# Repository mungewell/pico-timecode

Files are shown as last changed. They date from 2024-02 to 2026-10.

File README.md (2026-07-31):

# What is 'Pico-Timecode'?

'Pico-Timecode' is an Open-Source solution for LTC Timecode, using the RP2040's PIO blocks to count time divisions and render the LTC waveform. It works with all common frame rates, with/with-out Drop-Frame operation. It also has the ability to read LTC from an external device, and sync to it.

_LTC (sometimes refered to as SMPTE Timecode) is used in the TV/Movie industry as a way to synchronize video and audio recordings, it offers improvements in workflow and (most importantly) decreases overall editing time._

Some pro-consumer/professional Timecode devices use wireless links; Pico-Timecode is 'old skool' it uses a cabled connection to record the LTC signal onto an audio track of your camera or audio recorder. This audio waveform can later be processed and used to align multiple clips. If your device supports a true LTC input the data will be written directly as meta-data into the file(s).

For more information, check out the [Wiki.](https://github.com/mungewell/pico-timecode/wiki)

# Hardware

This technology has been implemented in 2 custom PCBs; Firstly the (now renamed) 'PT-Papa' board based around the (full sized) Raspberry Pico board, with Waveshare OLED screen module and input/output connectors.

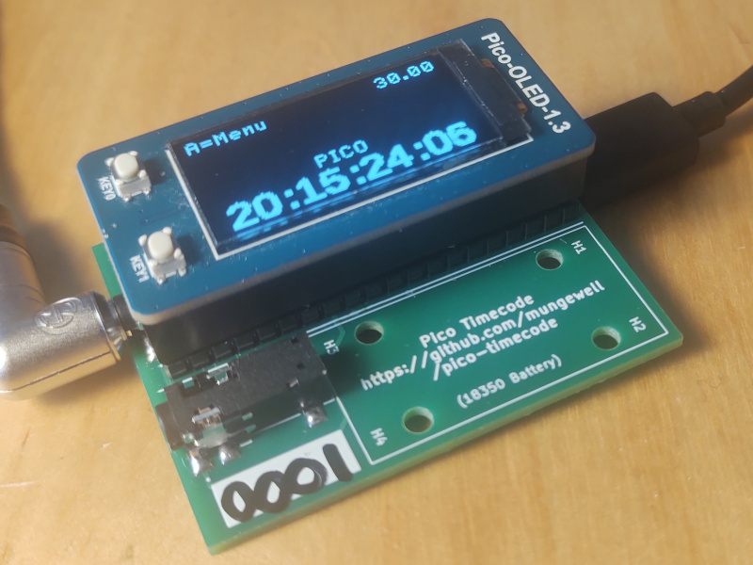
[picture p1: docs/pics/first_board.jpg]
'pt-papa' board


Secondly with the 'PT-Thrifty' board based around the (mini sized) Waveshare RP2040-Zero. 'PT-Thrifty' aims to make LTC accessible to DIY/budget film-makers, and thus it uses a minimum of components. It has a UI with single button and RGB LED, the control of the device is achieved by navigating through a [UI 'map'](https://github.com/mungewell/pico-timecode/blob/main/docs/pics/PT_Thrifty_UI.png) of states. 

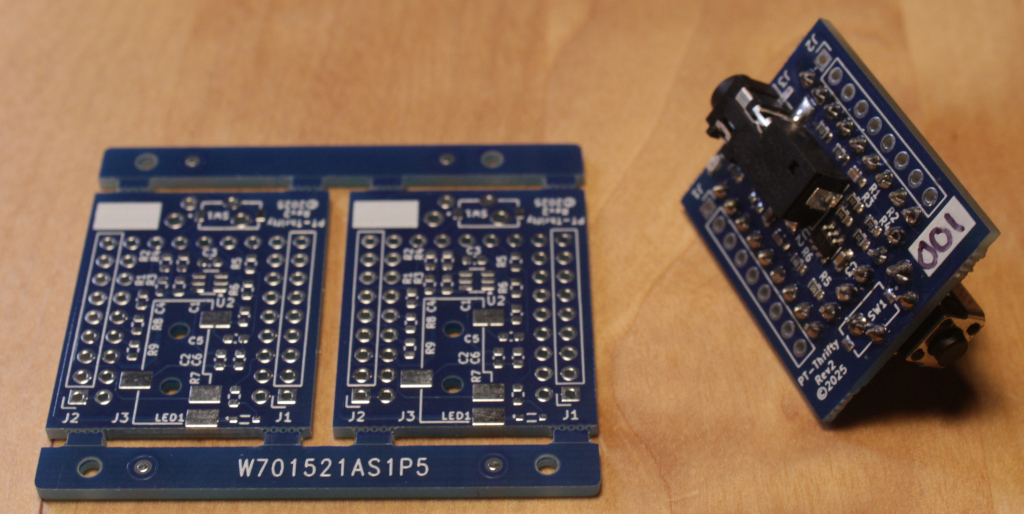
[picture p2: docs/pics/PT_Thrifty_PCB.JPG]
'pt-thrifty' board


There are some demonstrations of 'PT-Thrifty' [here.](https://www.youtube.com/playlist?list=PL1t1GwpUNc-VbEAXxscaxrPQlrt16c4yX)

# DIY yours now...

As the project is Open-Source, it's intended to be customized for other implementations.

The code as it is can be run on any RP2040 board, though may need customization for particular use cases. The easiest/fastest route to try it out is to use the PT_Thrifty '.UF2' files on the releases page, these can be run on a 'naked' Pico and will even sync LTC between multi Picos - albeit it at 3.3V TTL level. You will need at least a mininal amount of interface circuitry to record the signal on your camera or audio recorder.

I recomend replacing the XTAL on the Pico with a TCXO, but once 'calibrated' even the XTAL will hold time OK for a few hours.

To install the code to your Pico from source, at minimum you need to copy/install the `libs` directory, `pico-timecode.py` and **either** `pt_papa.py` or `pt_thrifty.py` (which should be renamed as `main.py` so that it runs at boot time).

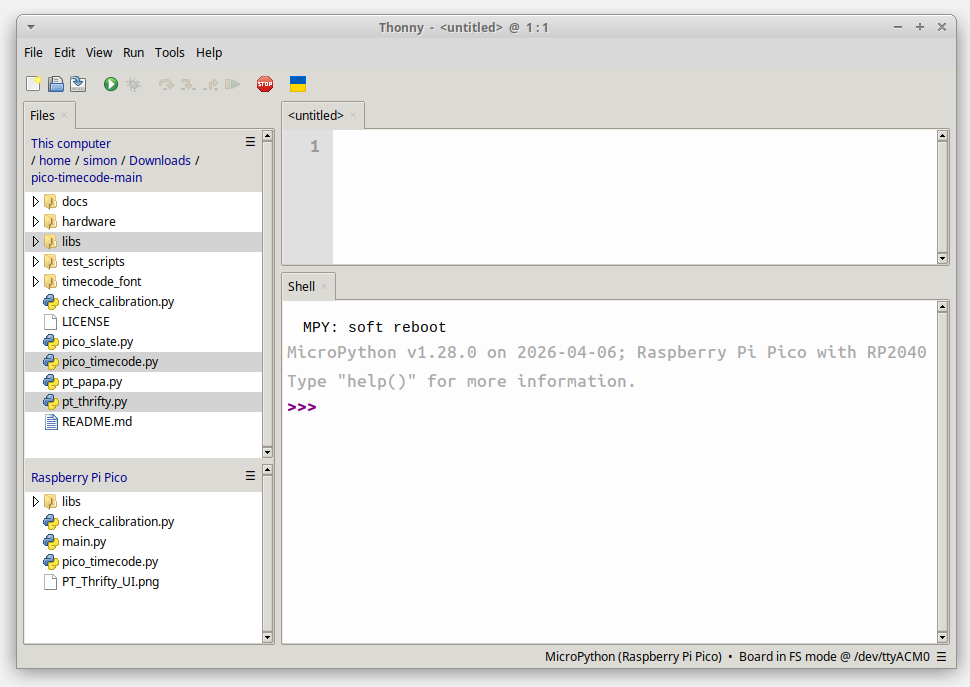
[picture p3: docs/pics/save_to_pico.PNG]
Install the code


# Why?

Why am doing this? Primarily because it's a fun challenge. I've been interested in Timecode for a while and the PIO blocks on the Pico are very powerfull. I am debating whether to offer pre-built hardware for purchase, *at very reasonable costs*.

You can follow the project on [Instagram.](https://www.instagram.com/picotimecode/)

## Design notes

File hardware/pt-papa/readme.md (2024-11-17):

Work is starting on PCB Rev2, for a while these files may be incomplete. You can access the
Rev1 PCB here:

https://github.com/mungewell/pico-timecode/releases/tag/PCB_Rev1

Ideas for future:

- 2x button on the bottom side, for replicating A & B when used with RP2040-LCD-0.96

- pull down 0R on U2/5 nCS, to allow 3rd party to wire line if SD0 is also used for other devices.

- add battery holder connections/through holes

- connections for Digi-Slate (extra) 8x 7-seg LED.

    This lib looks very interesting:
    https://github.com/smittytone/HT16K33-Python

    display count when switch is open, then hold for 2s once closed, then turn off
    possibly display UB, though could only do Digits/BCD.

    would need I2C (GP0, 1) and GPIO (GP2), plus GND/3.3v/VSYS

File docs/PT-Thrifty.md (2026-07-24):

# The PT-Thrifty is the 'lowest cost Timecode'.

PT-Thrifty has a single 3.5mm jack, from power on this outputs LTC
timecode. At different times of operation the 3.5mm jack becomes an
input, so that the PT-Thrifty can be 'Jam-Synced' from another LTC 
device.

User interface is a single button and a RGB LED, with some actions
requiring connecting/dis-connecting the 3.5mm jack.

There is a 2nd LED next to the 3.5mm jack. This provides a 1PPS flash
from the internal LTC timers at the start of Frame-0. As this is driven
directly its timing is exact, but some commercial units (ie: UltraSync)
choose to blink on Frame-11 for some reason... this can be configured through the `libs/config.py' file.

PT-Thifty is designed to be _LOW COST_, so it does not include battery
or other features that are technically possible (although these can 
be added to your DIY-ed version). The unit needs to be (and remain) externally powered for the duration 
of the shoot. If power is lost the unit will need to be Jam-Synced again.

Note: the 'Info' RGB will double-flash if the unit has previously been Jam-Synced.

[Video Demo](https://youtube.com/shorts/oo_elmEAXs4?feature=share)

# Map of the UI

In pictorial form the UI looks like:

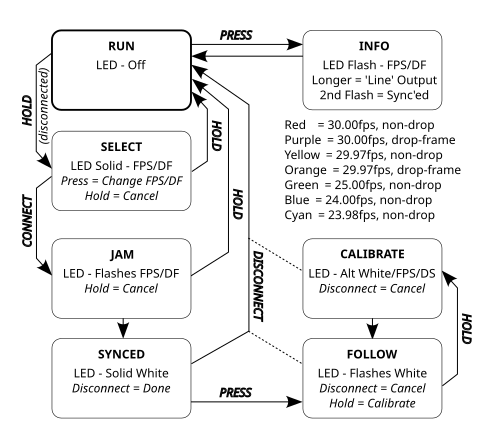
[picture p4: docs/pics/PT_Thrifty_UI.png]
Map


## Run, and Info

When initially powered up, the PT-Thrifty will start outputing LTC
timecode - this is NOT schronized with anything, just a free running
clock/counter.

Upon power up the RGB LED will flash a colour to inform the user what 
FPS and DropFrame configuration is active:

- Red 	= 30.00fps, non-drop
- Purple	= 30.00fps, drop-frame
- Yellow	= 29.97fps, non-drop
- Orange	= 29.97fps, drop-frame
- Green	= 25.00fps, non-drop
- Blue	= 24.00fps, non-drop
- Cyan	= 23.98fps, non-drop

Note: Some Pico boards use 'RGB' and some use 'GRB', this is configurable and should be changed if the sequence of FPS colours is not as above.

At any time during 'Run' the user can press the button to be reminded
of the current configuration ('Info').

To 'Jam' to another unit, disconnect the 3.5mm jack and press-and-hold 
the button until the LED becomes a steady colour. Then connect the 3.5mm
jack from the 'Master LTC', the LED will flash the colour and then become
solid white when the 'Jam' is complete.

Note: once solid white is displayed the internal time is set, but the LTC 
is not output until the 3.5mm jack is disconnected, and then the connection 
to camera/recorder is remade. Then PT-Thrift will then output LTC.

## Output Level

PT-Thrifty has two output levels: by default 'Mic' (~80mV pk-pk) and, optionally, 'Line' (1V pk-pk).

In order to change the output level the unit must be power-cycled. The
output level is toggled 'Mic' <-> 'Line' when the button is held during 
booting, and the current level is indicated during 'Info'.

The 'Info' flash is longer (0.3s vs 0.1s) when the output level is 'Line'. *The 2nd 'Jam-Synced' flash will remain at 0.1s duration, as a comparison aid.*

## Changing FPS and Drop-Frame configuration

As part of the 'Jam' process the FPS and Drop-Frame configuration can
be changed. From 'Run', hold the button until LED is solid colour and then
each press of the button will cycle through the available configurations.

When the desired configuration is reached, connect the 3.5mm jack to 
start jamming with the new configuration. This new configuration will be 
remembered for the next time PT-Thrifty powers on.

Note: During this 'Pre-Jam' selection, the internal LTC time is still
correct. If a user enters this state and changes their mind they can 
long-press the button to return to the 'Run' state, without loosing LTC synchronization. 

Note: If the unit enters the 'Jam' mode (flashing Colour), then the 
internal **LTC time is lost** and the unit will NOT be Synchronised until
it is Jam-Synced with an external unit.

## Calibration

Typicaly the TCXO module inside PT-Thrifty is accurate to under +/-0.5
frames of drift over a 12 hour period.

However if the user has DIY-ed a board, they may be using the stock/passive
XTAL that the RP2040 boards normally have. This will be inaccurate, but
can be 'Calibrated' to match a more accurate source such as commercial
LTC device.

A calibrated DIY/XTAL unit is only accurate for a few hours, and is likely 
temperature dependant. If the user goes between a warm and cold ambient 
temperature, the LTC will drift away faster from the correct value.

Once the 'Jam' has completed, shown by solid white LED, a button press
will enter 'Follow' mode. During 'Follow' the LTC produced by PT-Thrifty
will be adjusted to match incoming LTC.

Disconnect the 3.5mm jack to return to 'Run' mode.

Note: during 'Follow' the rate of the incoming LTC is tracked, PT-Thrifty does not update if there is a "jump change" in the incoming LTC.

Note: as the LTC is not output at this time, this is just informative
and the relationship of RX vs. TX LTC will be relayed to the serial port.

A long-press will enter 'Calibrate' mode, which like 'Follow', the internal 
LTC rate will be adjusted to match incoming LTC rate. This is indicated with 
alternate White/Colour flashing.

After ~10mins of processing, the new calibration value will be stored and 
the unit will return to 'Follow' mode. Disconnect the 3.5mm jack to 
return to 'Run' mode.

Note: To clear a calibration the user needs to enter 'Calibration' mode, 
but then disconnect the 3.5mm jack BEFORE it completes the calibration 
process.

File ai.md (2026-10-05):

AI declaration: Simon Wood (simon@mungewell.org), 2026-10-05.

Within are my views on AI contributions to this project. 

Open-Source relies on the legal framework of copyright to enforce it's licenses. And for that reason I will not accept submissions from AI-agents or code from Generative-AI, as the former can not make legal assignments of copyright and the later can not prove where it 'sourced' the code/information.

Using this other (random) reference:
- https://www.visidata.org/blog/2026/ai/
- https://web.archive.org/web/20260925032610/https://www.visidata.org/blog/2026/ai/

The 'levels of AI' in submissions are limited to:
- Level 0: Human did not use AI at all
- Level 1: Human asked chatbot for ideas
- Level 2: Human coded with minor assists

Ultimately this is my project, I reserve the right to reject any submissions.

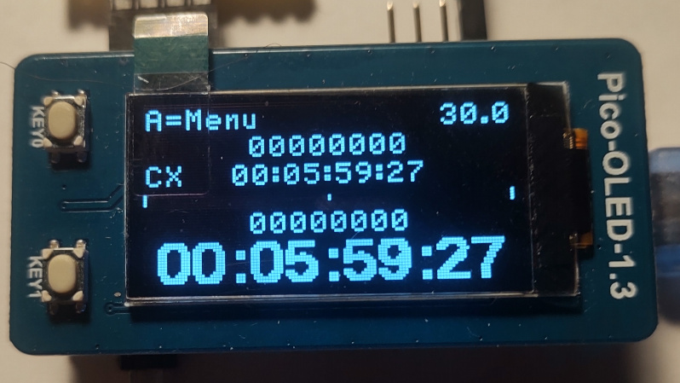
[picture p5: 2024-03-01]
docs/pics/prototype_hardware.jpg

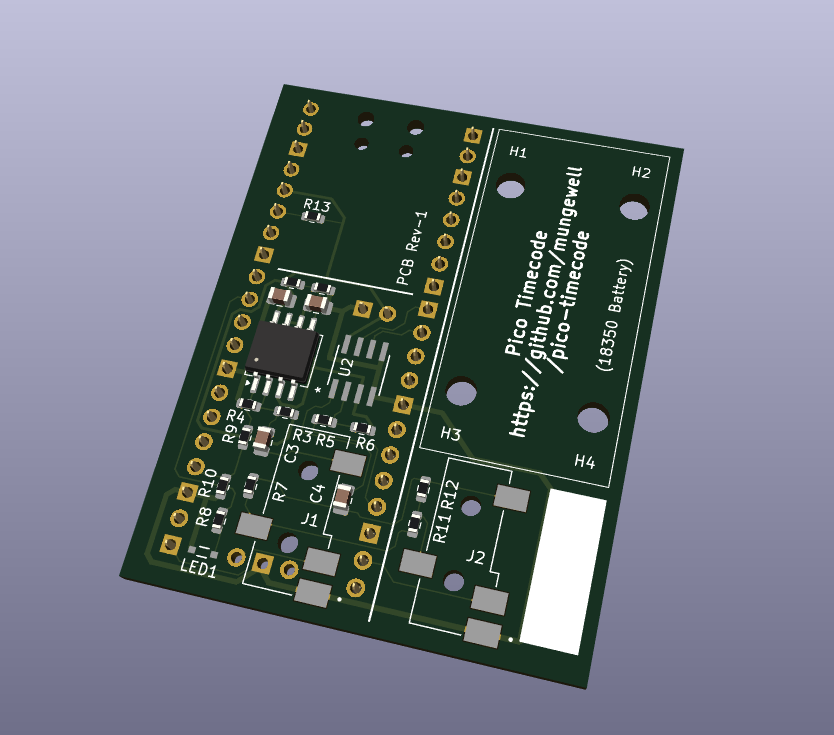
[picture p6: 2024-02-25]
hardware/pt-papa/output_pcb_rev1/rev1-render.png

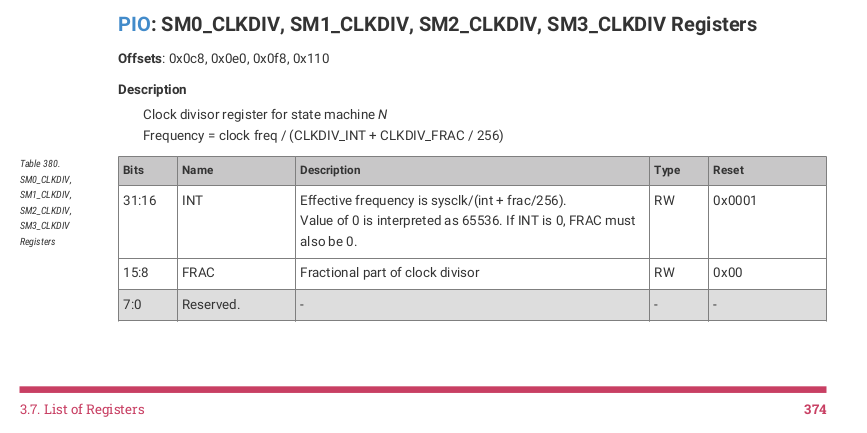
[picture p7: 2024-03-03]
docs/pics/clockdiv_register.png

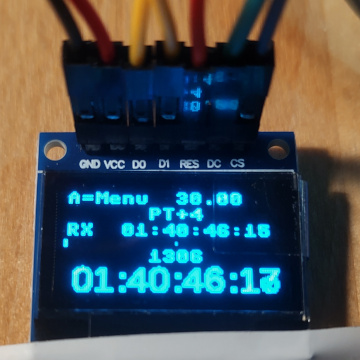
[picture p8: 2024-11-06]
docs/pics/ssd1306_display.jpg

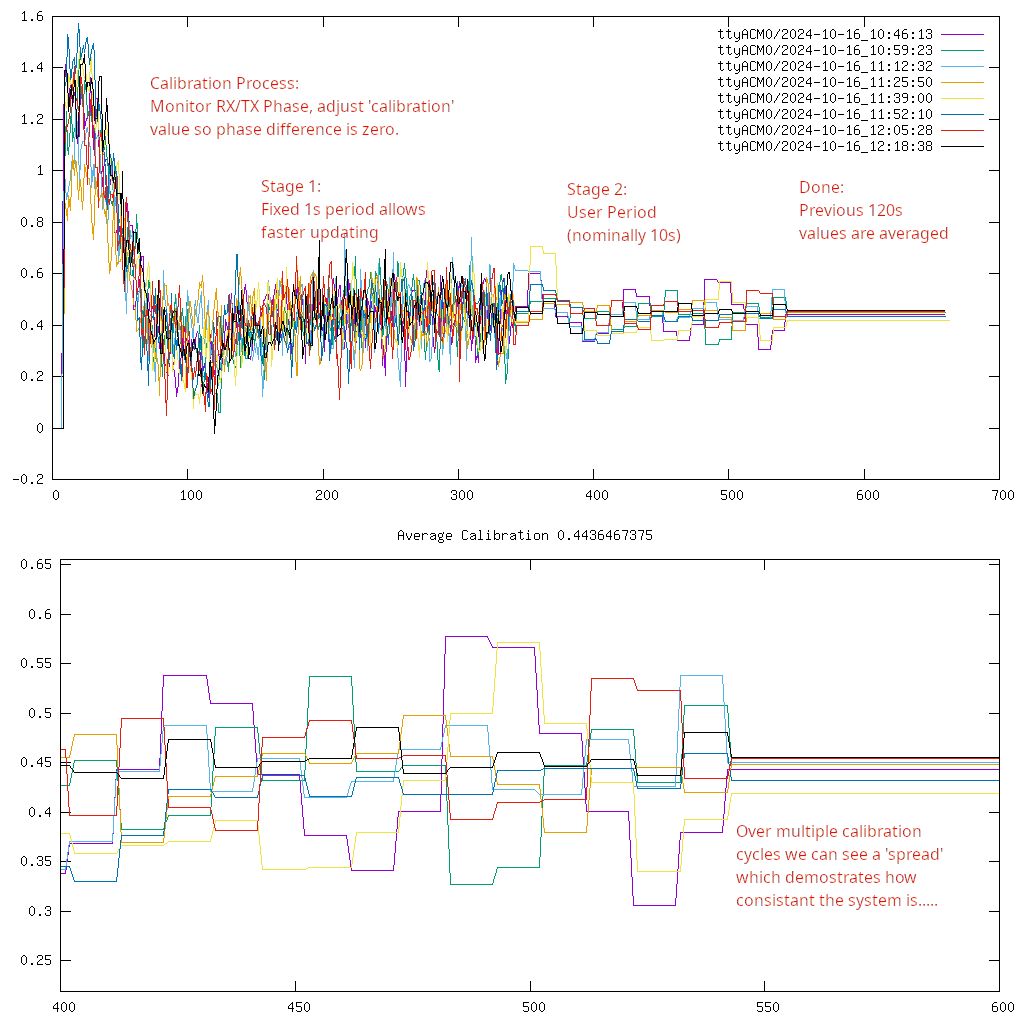
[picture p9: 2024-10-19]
docs/pics/cal_ttyACM0_anot.png

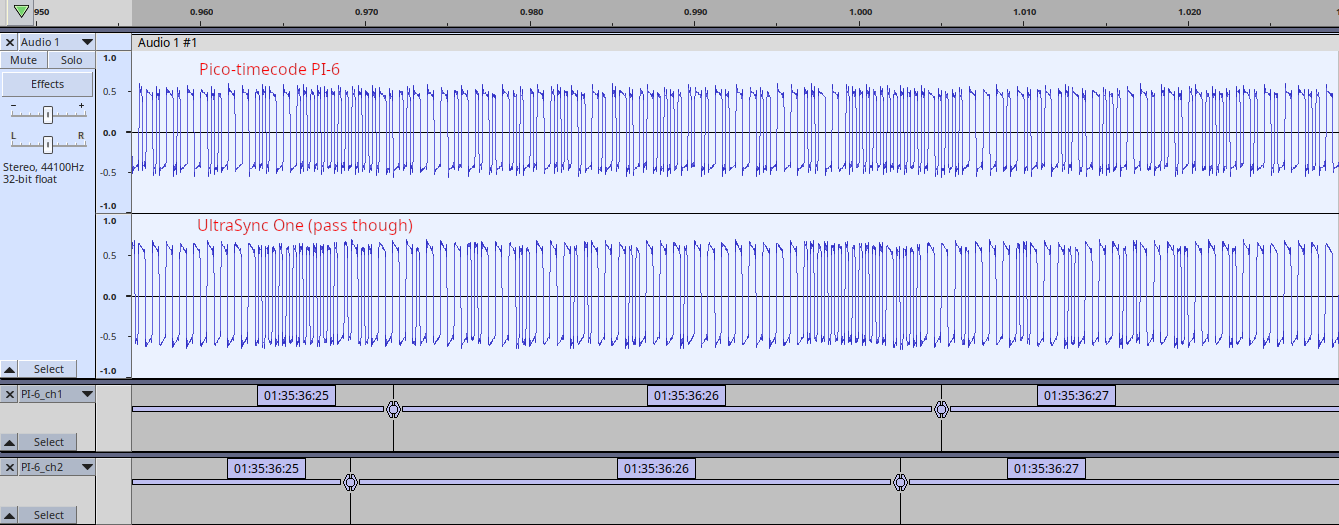
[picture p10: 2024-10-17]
docs/pics/PI-6_sample_audio.png

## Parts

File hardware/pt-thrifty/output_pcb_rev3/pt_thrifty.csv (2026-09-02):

Id | Designator | Footprint | Quantity | Designation | Supplier and ref
1 | C1, C2, C5, C81, C82 | C_0603_1608Metric | 5 | 1uF
2 | C3, C4 | C_0603_1608Metric | 2 | 100nF
3 | C7, C8 | C_0603_1608Metric | 2 | 10uF
4 | D1, D2 | D_0603_1608Metric | 2 | D
5 | DI1, DI2, DI3, DI4 | KWA-541XVB | 4 | KWA-541XVB
6 | J1, J2 | PinSocket_1x09_P2.54mm_Vertical | 2 | Conn_01x09
7 | J3 | CUI_SJ-43514-SMT-TR | 1 | SJ-43514-SMT-TR
8 | J4 | PinSocket_1x08_P2.54mm_Vertical | 1 | Conn_01x08
9 | J5 | PinSocket_1x04_P2.54mm_Vertical | 1 | Conn_01x04
10 | J6 | PinSocket_1x02_P2.54mm_Vertical | 1 | Conn_01x02
11 | J81 | JST_PH_B2B-PH-K_1x02_P2.00mm_Vertical | 1 | Conn_01x02
12 | J99 | Amphenol_F32Q-1A7x1-11010_1x10-1MP_P0.5mm_Horizontal | 1 | Conn_01x10
13 | LED1 | LED_LTST-S220GKT_LTO | 1 | LTST-S220GKT
14 | R1, R2, R14, R82, R83, R84, R90, R97, R98, R99 | R_0603_1608Metric | 10 | 100R
15 | R3, R4, R10, R11, R12, R13, R91, R92, R93, R94, R95, R96 | R_0603_1608Metric | 12 | 100K
16 | R5, R6, R8, R81 | R_0603_1608Metric | 4 | 2.00K-1%
17 | R7 | R_0603_1608Metric | 1 | 330R
18 | R9 | R_0603_1608Metric | 1 | 2.49K-1%
19 | R15, R16, R17, R18 | R_0603_1608Metric | 4 | 0R
20 | R20, R21, R22, R23, R24, R25, R26, R27 | R_0402_1005Metric | 8 | 0R
21 | R28, R29 | R_0603_1608Metric | 2 | 10K
22 | R30, R31, R32, R33, R34, R35 | R_0603_1608Metric | 6 | 47K
23 | SW1, SW2, SW3 | SW_Tactile_SPST_Angled_PTS645Vx31-2LFS | 3 | SW_Push_Shielded
24 | TP1 | TestPoint_THTPad_1.0x1.0mm_Drill0.5mm | 1 | TestPoint
25 | U2, U3 | SOT-23-6 | 2 | MCP6273T
26 | U4, U5 | SOIC28-1.27-11.5X17.5MM | 2 | HT16K33A-28SSOP
27 | U80 | SOT-23-5 | 1 | MCP73832-2-OT

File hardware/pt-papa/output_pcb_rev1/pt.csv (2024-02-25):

Source: | C:\Users\swood\hardware\pt\pt.kicad_sch
Date: | 2/24/2024 8:12:39 PM
Tool: | Eeschema 7.0.11
Generator: | C:\Program Files\KiCad\7.0\bin\scripting\plugins/bom_csv_grouped_by_value.py
Component Count: | 20
Collated Components:
Item | Qty | Reference(s) | Value | LibPart | Footprint | Datasheet | DNP | MANUFACTURER | MAXIMUM_PACKAGE_HEIGHT | PARTREV | SNAPEDA_PN | STANDARD
1 | 4 | C1, C2, C3, C4 | 10uF | Device:C | Capacitor_SMD:C_0805_2012Metric | ~
2 | 1 | H4 | MountingHole | Mechanical:MountingHole | MountingHole:MountingHole_3mm | ~
3 | 2 | J1, J2 | SJ-43514-SMT-TR | SJ-43514-SMT-TR:SJ-43514-SMT-TR | SJ-43514-SMT:CUI_SJ-43514-SMT-TR |  |  | CUI Devices | 5.3mm | 1.05 | SJ-43514-SMT-TR | Manufacturer Recommendations
4 | 1 | LED1 | LTST-S220GKT | LTST_S220GKT:LTST-S220GKT | footprints:LED_LTST-S220GKT_LTO | LTST-S220GKT
5 | 5 | R1, R2, R3, R4, R6 | 10K | Device:R | Resistor_SMD:R_0603_1608Metric | ~
6 | 2 | R5, R10 | 150K | Device:R | Resistor_SMD:R_0603_1608Metric | ~
7 | 1 | R8 | 330R | Device:R | Resistor_SMD:R_0603_1608Metric | ~
8 | 2 | R9, R11 | 0R | Device:R | Resistor_SMD:R_0603_1608Metric | ~
9 | 1 | U1 | LM358 | Amplifier_Operational:LM358 | Package_SO:SO-8_5.3x6.2mm_P1.27mm | http://www.ti.com/lit/ds/symlink/lm2904-n.pdf
10 | 1 | U2 | MCP6S91-E/SN | MCP6S91_E_SN:MCP6S91-E_SN | MCP6S91_E_SN:SOIC8-N_MC_MCH | MCP6S91-E/SN

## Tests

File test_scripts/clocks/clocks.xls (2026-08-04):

Framerate | Freq | Divider | Integer | Fractional | check if precise |  | Up Adjust | Down Adjust | PPM
60 | 153600 | 1171.875 | 1171 | 0.875 | 224 | 0 | 180000600 | 179999400 | 3.333333333e-06
59.94005994 | 153446.5534 | 1173.046875 | 1173 | 0.046875 | 12 | 0 | 180000599.4 | 179999400.6 | 3.33000333e-06
50 | 128000 | 1406.25 | 1406 | 0.25 | 64 | 0 | 180000500 | 179999500 | 2.777777778e-06
49.95004995 | 127872.1279 | 1407.65625 | 1407 | 0.65625 | 168 | 0 | 180000499.5 | 179999500.5 | 2.775002775e-06
30 | 76800 | 2343.75 | 2343 | 0.75 | 192 | 0 | 180000300 | 179999700 | 1.666666667e-06
29.97002997 | 76723.27672 | 2346.09375 | 2346 | 0.09375 | 24 | 0 | 180000299.7 | 179999700.3 | 1.665001665e-06
25 | 64000 | 2812.5 | 2812 | 0.5 | 128 | 0 | 180000250 | 179999750 | 1.388888889e-06
24.97502498 | 63936.06394 | 2815.3125 | 2815 | 0.3125 | 80 | 0 | 180000249.8 | 179999750.2 | 1.387501388e-06
24 | 61440 | 2929.6875 | 2929 | 0.6875 | 176 | 0 | 180000240 | 179999760 | 1.333333333e-06
23.97602398 | 61378.62138 | 2932.617187 | 2932 | 0.6171875 | 158 | 0 | 180000239.8 | 179999760.2 | 1.332001332e-06
Bits in Frame | CPU Freq |  |  | 1/256 Fractions |  |  | Adjust | 1
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

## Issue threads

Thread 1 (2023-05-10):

Can a camera Mic port provide enough 'Phantom' power for RP2040?

mungewell, 2023-05-10:
Thought crossed my mind, can we power the Pico (or other board) from the 'phantom power' provided via camera's mic port?

If so, we could make 'pico-timecode' into a dongle to plug directly in. Once sync'ed it could remain attached to/power by camera.

There is this small variant of a Pico board, which can also run micro-Python....
https://www.pishop.ca/product/tiny-2040-2-mb/

mungewell, 2024-03-01:
Background reading/watching...
https://www.youtube.com/watch?v=3PH9jzRsb5E

Xander1125, 2024-03-24:
This is not ideal because any power down of the camera or disconnection of the cable would result in a desync of the timecode devices. Typically timecode allows the user to power the camera down multiple times during a shoot while remaining sync. This encourages all-day shooting for events like weddings or other big shoots.

Also, phantom power won't be provided by the built in mic port of many cameras, if not all. An xlr connection is typically needed, because the pins remain separate even when connecting or disconnecting the cable. A 3.5mm or TRS cable could short circuit if the user is connecting or do connecting the camera while phantom power is active.

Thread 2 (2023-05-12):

Jamming/Processing RX data - relative to the start of frame.

mungewell, 2023-05-12:
In my world Frame XX starts with the first bit of the frame, but when we're receiving the (same) data we can't process it until the end of the frame - just before the sync word.
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

So in-order the Jam correctly we need to automatically increase the Frame number, and apply to the TX engine.

Most of the time we would want to increase by two, as we're likely before the end of the frame. However there is a chance that we're between end of frame and start of next. We'll have to look at the timing of these points (relative to CPU clock) to see if we increase by one or two.

If we're in the 'Danger Zone', then perhaps we should just defer the Jam for another Frame/time.

mungewell, 2023-05-12:
We also should use the same logic to correct the 'RX Monitor' display.

mungewell, 2023-05-12:
Also, if we're too close to the star of the next frame, there is a chance that the FIFOs will not relay the data to PIO engine fast enough - missing the correct moment to sync.

mungewell, 2023-05-13:
Was able to get interrupts working, so now have some reference data on start of frames - both for TX, and RX (decoding itself).

```
now                         tx_tick   rx_tick
884500784 RX: 00:00:00:00   884504768 884497521
884511062 RX: 00:00:00:00   884537955 884537416
884549569 RX: 00:00:00:00   884571273 884570800
884578791 RX: 00:00:00:01   884571273 884570800
884583281 RX: 00:00:00:01   884604597 884604126
884612167 RX: 00:00:00:02   884604597 884604126
884616559 RX: 00:00:00:02   884637936 884637465
884645462 RX: 00:00:00:03   884637936 884637465
884649968 RX: 00:00:00:03   884671255 884670784
884678755 RX: 00:00:00:04   884671255 884670784
884683141 RX: 00:00:00:04   884704606 884704131
884708144 RX: 00:00:00:05   884704606 884704131
884716381 RX: 00:00:00:05   884737944 884737467
884745440 RX: 00:00:00:06   884737944 884737467
884749889 RX: 00:00:00:06   884771266 884770802
884778875 RX: 00:00:00:07   884771266 884770802
```

mungewell, 2023-05-13:
Oh boy, Open-Source is awesome.... I can use `ltcdump` and Audacity to do the heavy lifting here. Record a section with Left/Right being TX/RX LTC data.

Process with:
```
$ ~/ltc-tools-github/ltcdump -a -c 2 jam.wav  > jam_rx_label.txt
```

And open in Audacity.
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

For the curious, without fixing anything, we have data 'off by one' frame and a delta in timing of 0.000997s.
```
$ grep "00:00:13:07" *_label*
jam_rx_label.txt:10.001338	10.034649	00:00:13:07
jam_tx_start_muted_labels.txt:10.035646	10.068957	00:00:13:07
```

mungewell, 2023-05-13:
Something is not making sense.

The 'Sync' is supposed to be triggered from IRQ into 'sync_and_read' which immediate sets the Output Pin (Pin 21) and this feeds in to the Trigger, which in turn lets all the TX machines run from their holding point.

The IRQ is from 'decode_dmc', and is set immediately after the input pin goes high/low at the _start_ of the bit cycle (before it even knows what value the bit will be).

There is no way that this process is taking 0.000997s, which is around 38 cycles... we are clocking at 16x bit clock, so about 2.3-ish bits. And indeed that delay seems to match the observed signals.

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

Is this another issue, perhaps with FIFO data not being auto-pulled, or with microPython being late to deliver the data into the FIFO?

mungewell, 2023-05-16:
I think that I found the issue here. Dispite what it says in the RP2040 datasheet, adding a delay to the `IRQ(clear, 5)` affects how/when the code waiting on a `IRQ(block, 5)` will trigger.

If I do the delay on a NOP after the IRQ it runs sooner.
```
def decode_dmc():
    label("initial_high")
    wait(1, pin, 0)
    irq(clear, 5)
    nop()[9]        # trigger sync engine, and wait til 3/4s mark
```

Without NOP:
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

With NOP:
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

This has been implement in HEAD, and I've also spend up the RX code to run at 32x bit clock.

Closing.

Closed 2023-05-16.

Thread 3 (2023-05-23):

Micro Adjust to compensate for XTAL inaccuracies

mungewell, 2023-05-23:
I have been looking at how we can bias the XTAL, to compensate for any inaccuracies between it and the 'other' devices in use.

We have a scheme where the PIO clock divider is toggled up/down by 1/256 fraction at a defined duty factor. This means that the clocks are slight faster/slower for a fraction of the time. With two Picos connected together we can see values of +0.1, -0.1 and -0.5 affect the synchronization (error bar) 10 minutes after Jamming.

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

The question is how do we measure the inaccuracy to figure out the correction....

mungewell, 2023-05-23:
For now you can set a hardcoded value here:
https://github.com/mungewell/pico-timecode/blob/main/pico_timecode.py#L517

This is the duty factor for the compensation, which is plus/minus one fractional clock. It's likely different duty factor will be needed for different framerates.

mungewell, 2023-05-24:
In a long term test, confirmed that the XTAL on device can be biased one way or the other. This is using a +/-1 fraction on the PIO clock divider for a duty cycle of ~60s period.

Between two devices (A -> B) the error bar value was recorded every minute, with no adjustments the devices were out-of-sync by 1 frame after 5hr 48mins, with A being ahead. In the following chart 'Blue' is uncorrected, 'Red' is the clock on B slowed further (increasing the rate of divergence) and 'Yellow' is the clock on B made faster (keeping them in sync for longer).

_In this case I don't know what the correct rate should be, only the comparison between the two. I'd suspect that both devices are off, just don't know by how much_

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

mungewell, 2023-05-26:
With further adjustment I was able to limit the XTAL drift to less than 3500us in 12hrs!
```
$ head A_to_B_30fps_super_fast.txt
00:02:00:05 77.77777
00:03:00:02 73.77777
00:04:00:05 37.77777
00:05:00:02 94.77777
00:06:00:05 81.77777
00:07:00:06 83.77777
00:08:00:02 58.77777
00:09:00:05 103.7778
00:10:00:04 103.7778
00:11:00:01 90.77777

$ tail A_to_B_30fps_super_fast.txt
11:52:00:06 3322.778
11:53:00:04 3309.778
11:54:00:05 3289.778
11:55:00:03 3320.778
11:56:00:05 3322.778
11:57:00:03 3310.778
11:58:00:05 3325.778
11:59:00:02 3291.109
12:00:00:04 3315.778
12:01:00:01 3355.778
```

It also occurred to me is that we might be able to actively monitor the delta/error bar when a source is connected, and change the adjustment to minimize the drift between two device. The second would then 'learn' the first's XTAL rate.

mungewell, 2023-06-02:
I was able to use 'Simple PID' to track the time delta between RX and TX (blue trace) and adjust the PIO dividers (red trace) so that the local clock rate exactly matched that of the external reference. This is set to happen automatically after a Jam, until the RX monitor screen is closed - at which point the adjustment is locked/held.

On my test bench the Pico tracked the signal from my SG-4 Blackburst generator (with LTC produced by a Sync-IO).
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

The RX signal was tracked up to 7620s, after this the delta remains stable for a while. I think that the 'droop' is actually temperature related. The test equipment was near a west facing window, and may have been heated slightly by the sun... after a while the drift changes direction.
```
02:04:00:02 18.50002 2.368298 (0.01850002, 2.349541, 0.0002566667)
02:05:00:03 7.400015 2.361011 (0.007400016, 2.353981, -0.00037)
02:06:00:04 -4.699985 2.346058 (-0.004699985, 2.351161, -0.0004033334)
02:07:00:03 -1.099985 2.346058
02:08:00:04 1.700015 2.346058
```

The 'delta' then continues drifts, and is a whole frame late after 15 1/2hrs. Not bad indeed!
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
```
17:39:00:04 -253.9978 2.346058
17:40:00:02 -148.2979 2.346058
17:41:00:05 -36.69786 2.346058
17:42:00:04 106.3021 2.346058
17:43:00:02 170.6021 2.346058
17:44:00:02 167.3021 2.346058
```

I think the next improvement will be to use the hardware timer IRQ to modulate the PIO dividers, rather than doing this in `pico_timecode_thread()`.

mungewell, 2024-02-17:
After a long time away from the project, I'm back thanks to a fix in mircoPython everything seems to be working now.

I made a quick video on the clock accuracy, with compensation code working a group of 4 stock Pico's where within 4 frames 18hrs after Jamming. This is good, but probably not good enough... on with the XTAL replacement idea.

https://www.youtube.com/watch?v=ilfQTCmmGfg

mungewell, 2024-02-26:
In my latest changes to the code, it attempts to use a PID loop (just PI at the moment) to change the 'adjustment' value.

This 'adjustment' is fractional, the whole units are the steps of the fractional dividers and the fractional part is a time based modulation between adjacent values... meaning that X.5 is 50% duty factor between 1+0/128 and 1+1/128.

System is both noisy and slow (as it's display on OLED - which we could turn off). By default I'm modulating on a period of 10s, this might have to be extended to get more resolution in the modulation.

I had used a rolling average of the last N values of the micro-adjust value, but it seems that this is NOT usable - even the last 240 values still has not settled in to a value. I need to rethink that, anyone have suggestions?
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

Notes on above plot:

After ~4000 samples, I stopped calibration and the micro adjust locks into last (averaged) value. But just prior to this there are 'wild swings' so really this locked value could be anything  - slightly high or low means time will drift, but in this dataset we were drifted by 4bits after ~5hr (so actually pretty good).

mungewell, 2024-02-28:
I've improved the calibrations process, and added some scripts that collect/plot data so we can see what's happening.

It is not the first time that I see the unit selecting a wildly different value for it's 'adjust' value...
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

This may be related to the sync not being spot on when the unit starts with jam (as apposed to the user starting it).

mungewell, 2024-03-01:
I think I found the bug, that allowed the `adjust` value to be carried over from previous run - which if stopped during the high phase would mean a increase of one.

Latest calibration runs are pretty closely grouped, note that a difference of '1' is actually 1/256th of a frequency divider so these are actually a pretty small variance. If all these are averaged I guess that would be the true value.
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

mungewell, 2024-03-01:
From the last run of that plot I let the units run for 15hours, and they were still well within 1 frame accuracy...
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

Noted that this is NOT compensated for temperature.

Mechanism for 'micro-adjust' seems to be working well. Closing.

Closed 2024-03-01.

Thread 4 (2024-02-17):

Replacing XTAL with a more accurate one

mungewell, 2024-02-17:
It would seem that the stock XTAL (with might current code implementation) is not meeting the timing accuracy required - less than 1frame drift in 8hours.

Fortunately we can replace the XTAL with a more accurate TCXO module. I have 2 candidate parts:

- 12.0MHz - https://www.digikey.ca/en/products/detail/ilsi/i538-2o7-12-000-mhz/13682056
- 12.8MHz - https://www.digikey.ca/en/products/detail/txc-corporation/7N-12-800MBP-T/5222401

The 2nd is more accurate/precise, but with a slightly different frequency it might mean more work. The Pico's SDK has a override for building at different frequencies, so a custom build of microPython is likely needed. _The boot-rom also expects 12.0MHz, so using this part might mean that USB is not functional - and 'we' might have to rely on the SWD interface to program the board._

2nd part is also bigger....
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

mungewell, 2024-02-17:
Looking at the Pico's schematic, we can see that the XTAL is fed from the CPU via a series drive resistor (R14), and has a couple of matching caps (C16 and C17) - all of which are not needed for a TCXO module. Isolating the pads for the XTAL may give us more mounting options.
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

We can also pull a VCC from the caps next to the CPU.
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

mungewell, 2024-02-17:
Firstly - Highly recommended that you program the Pico BEFORE replacing components, that way you'll have indications of a working board (flashing LED/serial output/etc)...

12.0MHz **3V0** - https://www.digikey.ca/en/products/detail/ilsi/i538-2o7-12-000-mhz/13682056
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

This has a different footprint, we can see that the part should be **rotated**:

- PCB 1 (XOUT) = Pin 3 (Output)
- PCB 2 (GND) = Pin 4 (VCC) - This will need to be isolated, cut 4 links from pad to the ground plane
- PCB 3 (XIN) = Pin 1 (GND or NC) - Isolate by removing R14 from Pico
- PCB 4 (GND) = Pin 2 (GND)

Once the part is placed, add a small 'fly-wire' from small cap near CPU to Pin 4 of the TCXO module. Double check this is not shorted to ground before power-up.

**Note**: I have not yet performed this modification. I will attempt and remove this notice on success/failure.

I also now realized that I order the **WRONG** part for a 3V0  (not 3V3) VCC - oh well will try it anyway...

Mouser have an equivalent for 3V3, but wants to sell a full real of qty 3000.
https://www.mouser.ca/ProductDetail/ABRACON/I738-2P3-12.000MHz?qs=vmHwEFxEFR%2FD2ZfWbp716g%3D%3D

mungewell, 2024-02-25:
I have some results.... but not sure what it going on with some 'strangeness'.

Ultimately the 'accuracy' of the tracking is dependent on the system choosing the correct 'micro-adjust', where is modulates between adjacent fractional clock dividers. This is not (presently) compensated with temp, but that is something which might be possible.

I have recently changed this code, and now the system measures the 'phase' in frame duration - considering a wrap point at +/-0.5 (ie +/-40 bits of LTC data).

Anyhow.... I purchased an UltraSync One, and used this as the reference for testing.
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

Note: the point where 'micro-adjust' fixes is where I manually stopped calibration ('CX' mode), and restarted the monitor ('RX' mode).

So the one with the modified XTAL has a weird step, this was also seen in other data-sets from this board. But it does not seem to be present in non-modified board recorded at the same time. Regardless these plots (with a well chosen 'micro-adjust' value) show less than 4bits drift in ~5hrs (noting 80bits would be 1 frame).

My conclusion is that the (noted incorrect voltage) TCXO does not function correctly, and I will look at the alternatives - including the 12.8MHz I have on hand.

mungewell, 2024-03-05:
After spending some time digging through DigiKey, I think that this might be the 'Best' replacement...
"ECS-TXO-3225-120-TR"
https://www.digikey.ca/en/products/detail/ecs-inc/ECS-TXO-3225-120-TR/5357946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

There is also this (much more expensive) 12.8MHz part with really low PPM that will fit on the footprint.
"LFTCXO075793REEL"
https://www.digikey.ca/en/products/detail/iqd-frequency-products/LFTCXO075793REEL/8633985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

The following is a suggestion to modify the Pico PCB, should it ever be relaid:

_By adding 2 resistor footprints to connect to pin 2 of the XTAL, we could configure the board to take either a passive XTAL or a (user performed modification) TCXO. Only extra one resistor, connecting to ground, would be fitted for mass production._

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

mungewell, 2024-03-07:
Another candidate for the 'ugly mod' competition.... But this ($15) module is certainly holding it's own, showing less than 0.25 frames drift in 20hrs... though it's been at that value for hours, so maybe (at least some of) the drift is from initial warm up.
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

I also learnt a lot about how the USB doesn't work after you change XTAL frequency (to 12.8MHz for this). You can upload a special build of microPython with SWD interface, but the bootloader will be forever broken.

mungewell, 2024-03-20:
I was able to automate the testing of the XTAL, where performance is inferred from what the unit determines the 'calibration' value to be. This conclusively shows that the calibration DOES change with temperature.

The temp shown is not itself calibrated, but shows first plot at ambient (purple trace before I realized unit(s) were in the sun) and then second plot in the freezer.

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

Note: the fractional part of the calibration value represents modulating the between smallest fractional values of the PIO divider, ie between '1562+(128/256)' and '1562+(127/256)'.

_So a 'calibration delta' of 1.0, would be roughly equivalent to 2.5PPM XTAL variance._

Note: Temp vs Freq will not be linear, it depends on XTAL type. Some plots are 'S' shaped.

mungewell, 2024-10-17:
So after being away for a while, I have amassed more hardware and improved the code/testing scripts....
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

This takes a reference Timecode from the UltraSync One, splits/amplifies it to the 4 test units. The USB hub support power management, test scripts running on PC turn the units off/on to cycle/restart the calibration process and record the resultant data.

I have been running a few tests and this plot definitely shows a correlation between temp in the top plot and changing (computed) calibration in the lower plot.
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

 As the selected calibration moves from that required by particular XTAL and temperature, the resultant timecode will _slowly_ drift from perfect.

**Note:** the calibration value is defined in two parts, the integer value define the clock division value in the smallest possible difference in value (on the PIO clocks this is 1/256th of a divider). The fractional part of the calibration value is a duty factor, for dithering between one divider value, and the next (depending on sign).

So for 30fps, and a calibration value of -0.3 the code will dither between 1562.5 (1562 + 128/256) for 70% of the time and 1562.50390625 (1562 + 129/256) for 30% of the time. This gives apparently divisor of 1562.501171875, or about 1.00000075% speed adjustment.

mungewell, 2024-10-17:
A little glimpse into how calibration process runs....
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

mungewell, 2024-10-18:
I don't have a temp chamber, but I 'folded up' my test rig up and put in a box... along with a USB load tester to add 7.5W of heating.
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

This resulted in a little warming which **definitely** shows up in the calibration.
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

This pushed the calibration spread to quite a bit, over 1 unit!!
- "Minimum Calibration -0.5558637 "
- "Maximum Calibration 0.4578195 "
- "Average Calibration 0.03432039166666662 "

A Pico with the XTAL replaced with TCXO faired much better:
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
- "Minimum Calibration -0.3945614 "
- "Maximum Calibration -0.3196151 "
- "Average Calibration -0.3487558142857142 "

mungewell, 2024-10-22:
I modified a total of 6 boards with TCXO's, although I struggled with recreating my 'ugly' mod. I actually found it easier to stand the TCXO on end, and fly-wire 3.3v to power it... maybe not mechanically sound, but good enough for now.

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

I'm trying to understand the best way(s) to validate these, on the outset it looks like they are much better than the stock  XTAL, but there still seems to be some temperature variance....

mungewell, 2024-12-02:
So this is a thing now....
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

At 10'C
```
20241128_10C$ find . -name '*.py' -exec python3 {} \;
set yrange[-0.6668293000000001:-0.1901701]
set title "T006 Minimum : -0.4668293 "
set title "T006 Maximum : -0.3901701 "
set title "T006 Median : -0.42849970000000004 "
set title "T006 Average : -0.43838419999999995 "
set yrange[-0.8526231:-0.37128829999999996]
set title "T004 Minimum : -0.6526231 "
set title "T004 Maximum : -0.5712883 "
set title "T004 Median : -0.6119557 "
set title "T004 Average : -0.6167881100000001 "
set yrange[-0.5918292:-0.1394613]
set title "PT-3 Minimum : -0.3918292 "
set title "PT-3 Maximum : -0.3394613 "
set title "PT-3 Median : -0.36564525000000003 "
set title "PT-3 Average : -0.37087760000000003 "
set yrange[-0.7329938:-0.2569399]
set title "T002 Minimum : -0.5329938 "
set title "T002 Maximum : -0.4569399 "
set title "T002 Median : -0.49496684999999996 "
set title "T002 Average : -0.49475629000000004 "
```

At 40'C
```
20241128_40C$ find . -name '*.py' -exec python3 {} \;
set yrange[-0.6557084:-0.2088253]
set title "T006 Minimum : -0.4557084 "
set title "T006 Maximum : -0.4088253 "
set title "T006 Median : -0.43226685 "
set title "T006 Average : -0.43405330000000003 "
set yrange[-0.8128355:-0.3960141]
set title "T004 Minimum : -0.6128355 "
set title "T004 Maximum : -0.5960141 "
set title "T004 Median : -0.6044248 "
set title "T004 Average : -0.606632025 "
set yrange[-0.600455:-0.17753370000000002]
set title "PT-3 Minimum : -0.400455 "
set title "PT-3 Maximum : -0.3775337 "
set title "PT-3 Median : -0.38899435000000004 "
set title "PT-3 Average : -0.3892936000000001 "
set yrange[-0.7598024999999999:-0.35273879999999996]
set title "T002 Minimum : -0.5598025 "
set title "T002 Maximum : -0.5527388 "
set title "T002 Median : -0.55627065 "
set title "T002 Average : -0.5556236999999999 "
```

I also found that the Hub in my test setup doesn't apparently like the higher temps... as it locked up several times. :-(

mungewell, 2024-12-02:
Calibration sheet:
[calibration.pdf](https://github.com/user-attachments/files/17972316/calibration.pdf)

So the 'temp shift' in calibation depends on each unit (there may have also been temp variation within the oven), the **WORST** shift between 10'C and 40'C is 152ppb for 'average vs nominal/null calibration' and the typical is in the 10's of ppb.

_This is **SIGNIFICANTLY** above the shift we saw in calibration with the stock XTAL...._

For reference our target is: +/-0.5 frames in 8hrs; ie '8 * 3600 * 30fps = 864000 frames', so for accuracy we'd want '864000.5 / 864000 = 1.000000579' (around +/-0.6 ppm).

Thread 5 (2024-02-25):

Testing Rev-1 Hardware

mungewell, 2024-02-25:
I drew up a schematic and laid out a PCB for Rev-1 of the hardware, the audio interface is needed to amp/buffer the audio LTC signal into digital signals to/from the Pico.
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

This board is on order, and hopefully I will have 'hands on' in about a week...

The board is heavily dependent of the Pico footprint developed here, so a big thanks to that project:
https://github.com/ncarandini/KiCad-RP-Pico

The board is designed so that a Pico can be soldered directly (via castellated pins), or using pin headers. It's also zoned into 3 sections, where the battery/output and 'top of pico' can be removed to make a much smaller board. _There are Fit/No-Fit resistors to route the LTC output to the Right Channel of the input jack when using the smaller board._

I'm 100% certain I'll need to change the BOM, hopefully the PCB layout is workable. :-)

mungewell, 2024-02-25:
Some notes on component selection:

U1 is a fairly generic Dual Op-Amp, there are many substitutions possible, I ordered a few parts to try:

- LM358DR2G - https://www.digikey.ca/en/products/detail/onsemi/LM358DR2G/661123?s=N4IgTCBcDaIDIFkDMBWAHAEQEpgOIgF0BfIA
- LM2904S-13 - https://www.digikey.ca/en/products/detail/diodes-incorporated/LM2904S-13/5306172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
- RC4558IDR - https://www.digikey.ca/en/products/detail/texas-instruments/RC4558IDR/701928

U2 is more specialized, it is a programmable gain Amp controlled over a SPI-like interface. The intent is that Pico Timecode can have a controllable output level (or even turn it off).

- MCP6S91-E/SN - https://www.digikey.ca/en/products/detail/microchip-technology/mcp6s91-e-sn/716209

_The rest are 'jelly bean' and really component values can be substituted for whatever values you have available...._

mungewell, 2024-03-10:
Assembled the first Rev-1 board, a few component tweaks and it's functional... Woo Hoo!

salesmendesandre, 2024-05-10:
Have any adjustments been made to the hardware output files? I would be interested in ordering some assembled units from jlcpcb. Is the gerbers_2sides_pico.zip and pt.csv files sufficient or is some modification necessary?

mungewell, 2024-05-15:
The only major mistake is not having a ChipSelect for the Programable Amp, which I fly wired across to Pin 5. Other than that the board works OK, although this amp doesn't quite have enough difference in gain (between mic and line level).

I built the two layer board as, in the end, there was no difference in the cost between 1 and 2 layers. I have excess boards, which I could possibly share....

salesmendesandre, 2024-06-10:
Hello,

Today the boards I ordered arrived (when you responded I had already placed the order on PCBWay).

Regarding the components, I am using the ones you indicated in the CSV file. U1 -> LM358, U2 -> MCP6S91-E/SN. In the previous comment, you mentioned that the biggest issue would be not being able to control the ChipSelect of U2 from the microcontroller. As it is connected to GND, should it work without problems as it is currently connected, or is any modification necessary?

I am using the latest code found in the main branch of the repository. Sometimes the display shows an underflow error. Is it correct to use the latest version found in the repository? I have not yet been able to get a jam between two (I will keep trying in the coming days to see if there is any issue from when I soldered the components).

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

One more question: R12 and R7 are not necessary to mount, right? And R9 and R11 are soldered directly, correct?

Thank you very much for everything.

mungewell, 2024-06-13:
Nice, always liked black solder resist... though you should have gone with yellow silkscreen ;-)

Correct R7/R12 are not-fit, they are options to route audio/LTC if/when you only have the one connector. R11 is for 'bridging' the audio (say on camera mic) from J1 to J2.

R9 is a provision for tweaking signal from external LTC through AMP, this need to cross the reference voltage created with U1B pin 7.

Did you find lift the pin for the CS? Here's how I wired it across to GPIO5 of the Pico
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

You'll also want to be running this branch:
https://github.com/mungewell/pico-timecode/tree/pcb_rev1

I am a little distracted with other projects, but do intend to come back this one and validate those alternate XTALs.

salesmendesandre, 2024-06-14:
I have connected the CS pin to GPIO5, and now the output has TIMECODE LCT (I tested it with the application: https://timecodesync.com/monitor/).

I noticed there are differences between the resistors you are using compared to those listed in the CSV file along with the Gerber:

mungewell, 2024-06-15:
The schematic as 10uF, I think that 10nF might be a bit too small.
https://github.com/mungewell/pico-timecode/blob/main/hardware/output/schematic.pdf

The resistors aren't really critical, what you want to do is check that incoming LTC is causing the output of U1/1 is toggling, and this is a large enough swing that the PICO sees it as changing input.

For LTC output the programable amp doesn't have enough swing to change between Line and Mic level. The R5/R6 scale the signal down, and then the amp amplifies.... if you are not getting enough output for 2nd device to sync check the menus that the level is set as high as possible.

Do you have something that could scope the signals? Even a DVM would be helpful to check the DC levels of the reference/etc.

mungewell, 2024-06-15:
IIRC one of the amps I tried in the U1 position had difficult getting close to it's rails... I think I worked around this by adding a larger (330ohm???) at R9 to drop the signal more so that the Pico could 'see' it.

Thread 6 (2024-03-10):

Suggestions for Rev-2 Hardware

mungewell, 2024-03-10:
As development moves forward, I'll 'open the floor' to suggestions from every/anyone.

The following are on my list:

- Button footprints for displays without buttons
- Connections for I2C 7-seg display and switches, to assemble as Digi-Slate
- Battery holder, connector footprint and diode footprint
- Diode footprints for 'Bias-Power' (from camera audio input).

(I'll update list as suggestions come in).

salesmendesandre, 2024-03-10:
First of all, I would like to congratulate you for the development you are doing.

The device you are developing is designed to be used in cameras/recorders that have two audio channels (for example the right one for the microphone audio and the left one for the LTC).

I would like to propose you to include the possibility of including the necessary hardware so that it can be used in single channel devices without the need to disconnect the device and connect the microphone. In a single channel I suppose it would be possible to use the LTC at the beginning of the audio (x seconds) and then the normal audio. I don't know how this could be solved at the hardware level, but something that would change the output of the ltc to a direct connection to an input jack.

Once again I would like to congratulate you for the work you are doing.

mungewell, 2024-03-10:
Pass-though audio is supported now, if assembled in the construction with two 3.5mm connector. LTC output is on Tip/Left, Ring/Right is connected through to input connector (ie Mic).

I was tinkering with audio levels today and grabbed this screen shot (running in the 'Mic' output level, with Rode Video Mic attached to input).
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

I am not 100% sure what 'Bias' levels various camera/recorders output. My Sony cameras seem to out 2.7V on Ring (or TRS), my Tascam audio recorder output 2.2V on Ring.

Are there really devices which can't cope with stereo audio (even if external Mic is only mono)? Seems to me that switching would be a pain, and likely screwed up by operator on set.

As to electronically switching output between Mic and LTC; this might be possible if MCP6S93 was used, but it is a little bit more expensive ($2.21 vs $1.79).

Xander1125, 2024-03-24:
Although I don't think may would use the feature, the request above is for a toggle button that switches between mono pass through and LTC at the click of a button, so the user could start a clip with 10 seconds of timecode, then hit the button and use their mic without having to disconnect the LTC device from the signal chain.

I don't think many people will need this feature though, I've never seen a camera (at the level where someone is considering using a timecode workflow) with mono input only.

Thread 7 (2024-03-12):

Direct connection to Sony Multi-Interface Shoe?

mungewell, 2024-03-12:
I have a couple of Sony cameras without an audio jack, so I was wondering.... and ended up going down a massive rabbit hole.

The Multi-Shoe is described:
https://en.wikipedia.org/wiki/Multi_Interface_Shoe

It seems that (at least for simple devices) that the function is 'encoded' on the first 3 pins, as pull up/downs. It looks like for analogue audio that there are connections on:

- pin 4 - Mic GND
- pin 5 - Mic Right
- pin 6 - Mic Left

also

- pin 7/15/21 - Power GND
- pin 13 - Regulated power (3.1V)
- pin 14 - Mic Center(?)
- pin 17 - Un-reg Power (6.1-8.4V)

There are also some Digital Mic, with a digital connection to the camera(s), I presume that's the `GVIF_SDATA_N` / `GVIF_SDATA_P` alternate signals on the same pins.

There is a database of mics, and what they are supported on:
https://support.d-imaging.sony.co.jp/www/cscs/accessories/products.php?lang=en&area=gb&mnt=29

The real question is whether there's a cheap/easy way to get a compatible connector? Can we re-arrange the pins on a
Sony ADPMAA adapter?
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

mungewell, 2024-03-12:
There's another description here:
https://www.mhohner.de/sony-minolta/flashcomp_techref.php

And Sony make an adapter for some wireless kit:
https://www.bhphotovideo.com/c/product/1272753-REG/sony_smad_p3d_smadp3d_multi_interface_shoe_adapter.html

jyz0501, 2024-04-07:
神牛领夹麦和大疆麦克风 2 转换头已经有两款产品了

mungewell, 2024-10-27:
It also appears that the (older) Nex-3/5 also supported a hot shoe mic, but the connection is different (vertical plan, rather than horizontal).
https://support.d-imaging.sony.co.jp/www/cscs/accessories/compatibility.php?area=gb&lang=en&mdl=ECM-SST1&cat=3

Multi-shoe replacement connectors intended for repairing flash guns are now appearing on eBay for around $15. This might be hackable, to move pins to places we need them...
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

mungewell, 2024-10-27:
The XLR-K1M mic adapter has a flying lead connection to the hot-shoe, which is available as a spare part - though kind of expensive....
https://sonyparts.com/products/1-846-330-11?srsltid=AfmBOopgottERDM1yLpO9kUrYRDZwedYgeac7rRLAyB7CacxPdOG2-0m

mungewell, 2024-10-27:
There's also an extension cable for use with the XLR-K3M:
https://sony.encompass.com/item/12536372/Sony/1-002-838-11/

mungewell, 2024-10-27:
And replacement shoe for the XLR-K2M:
https://sony.encompass.com/item/10344058/Sony/A-2063-272-A/

mungewell, 2024-10-27:
This is the hot-shoe connector from the FX-3's TopHandle, XLRH1:
https://sony.encompass.com/item/12636514/Sony/A-5030-779-A/

https://www.partstown.com/sony/sonya-5030-779-a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

mungewell, 2024-11-09:
"Multi-shoe replacement connectors intended for repairing flash guns", I got some to experiment....

Firstly of note is that the connections are made via the FFC, which is inserted vertically into the body of the 'connector'. The wire pins of the MI seem to be bent at 90' (haven't disassembled yet) and make contact with pads off the FFC.
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

The pads which are Pins 1..3 on the MI are hard wired to (assumed) Pin 7, which would be ID 0b000. Assuming the ID pins are short to ground or open, the whole table would be:
```
Pin1	Pin2	Pin3	Meaning
ID3	ID2	ID1
G	G	G	Flash
G	G	O
G	O	G
G	O	O
O	G	G
O	G	O
O	O	G
O	O	O
```

The center portion of the connector is used for a floating pin (to hot-shoe center) which would block the pins that we'd want to connect to, but perhaps this can be modified. Maybe someone could 3D print a replacement part.

At least 'we' should be able to use this connection to probe out the possible IDs, I'll update the table if I figure anything out.

mungewell, 2024-11-28:
There's also this DJI adapter:
https://www.bhphotovideo.com/c/product/1816274-REG/dji_cp_rn_00000332_01_mic_2_camera_adapter.html

dylanreeve, 2025-08-11:
This AliExpress seller is listing a replacement shoe for the XLR-H1 audio adapter. It appears to be a full MI-pinned show. The XLR-H1 is a dual channel XLR input.

https://www.aliexpress.com/item/1005008851735668.html

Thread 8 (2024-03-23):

'Phase' glitches with high precision TCXO - 12.8MHz

mungewell, 2024-03-23:
When monitoring an external device, with a Pico modified with high precision TCXO I see glitches.
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

These are not 'real' in the sense that (presumably) the relative phases of TX and RX are not changing for single cycles. Maybe there is something weird with TX and RX interrupts triggering at exactly the same time?

mungewell, 2024-12-02:
closing, as probably nothing to do here....

Closed 2024-12-02.

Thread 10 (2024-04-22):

Calibration: off by 1 error

mungewell, 2024-04-22:
As mentioned on #4 we have a way to assess the XTAL accuracy by performing a calibration process, and logging the results.

I have/am writing scripts to automate this process and previously noted that a unit could settle on calibration values which differ by 1 unit - which represents 1/256 fractional division of the CPU clock.

I previously though that this was a set-up issue (ie only at start), but now I have a couple of logs where the calibration value changes during the process to 'jump' between the two values. This suggests that there is something wrong with the way the code monitors/tracks the input (from UltraSync)...

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

and
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

Note: Multiple units monitoring the same input signal, so I don't think that this is the UltraSync glitching.

mungewell, 2024-04-22:
Also note that '1 unit' represents a change of around 2PPM, this is a tiny inaccuracy.

mungewell, 2024-10-17:
Pushed changes to the 'pcb-rev1' tree, which I think solves this issue.

mungewell, 2024-10-26:
Haven't see this occur in recent testing of Rev2.0,closing.

Closed 2024-10-26.

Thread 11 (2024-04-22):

Calibration: missing time-stamp

mungewell, 2024-04-22:
In logging the data during the calibration process, I notice that sometimes the timestamp is missing... which caused glitches in the plotted data

```
[548.866017 0.988578] 02:27:30:01 0.0006966665 -3.433942e-05 -0.6695886 23.21196
[549.974362 1.108345] 02:27:31:04 -0.0008033332 -5.246907e-05 -0.6695886 23.21196
[550.956958 0.982596]  -0.0004733335 -2.879265e-05 -0.6695886 23.30559 <----- double space on this line
[551.936826 0.979868] 02:27:33:03 0.0003666663 -6.569061e-05 -0.6695886 23.30559
[552.918270 0.981444] 02:27:34:02 -0.0007733335 -6.301473e-05 -0.6695886 23.30559
```

This is moderately common, and thus a pain to edit out...

mungewell, 2024-12-02:
I have switched to a NeoTimer loop. So closing this bug for now.

Closed 2024-12-02.

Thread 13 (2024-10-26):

Calibration glitch with long run times

mungewell, 2024-10-26:
Testing with Rev2.0, and seen a glitch where the calibration appears to change during a long session. Ie. after multiple hours...

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

It looks like the process which toggles between two divider values is getting stuck. Normally Timer-2 would run for 10s, with Timer-1 running for a fraction of this - depending on the fractional part of the calibration value. The when Timer-2 terminates it re-setups Timer-1 and Timer-2.

However it seems that Timer-1 never restarts for some reason.
```
$ cut -d ' ' -f 8 2024-10-25_09\:13\:51 | uniq -c
...
      6 Timer(mode=ONE_SHOT,
      4 None
      6 Timer(mode=ONE_SHOT,
      4 None
      6 Timer(mode=ONE_SHOT,
      4 None
      6 Timer(mode=ONE_SHOT,
  28093 None
```

```
[1968.983111 0.955910] 12:37:31:00 0.003426666 0.0010681 -0.39968 26.58251 Timer(mode=ONE_SHOT, tick_hz=1000000, period=6003000) Timer(mode=ONE_SHOT, tick_hz=1000000, period=10000000)
[1969.981384 0.998273] 12:37:32:01 0.0005766665 0.0010728 -0.39968 26.58251 Timer(mode=ONE_SHOT, tick_hz=1000000, period=6003000) Timer(mode=ONE_SHOT, tick_hz=1000000, period=10000000)
[1971.004731 1.023347] 12:37:33:02 0.0006066663 0.0010922 -0.39968 26.58251 Timer(mode=ONE_SHOT, tick_hz=1000000, period=6003000) Timer(mode=ONE_SHOT, tick_hz=1000000, period=10000000)
[1972.028565 1.023834] 12:37:34:03 0.001326666 0.001107 -0.39968 26.58251 Timer(mode=ONE_SHOT, tick_hz=1000000, period=6003000) Timer(mode=ONE_SHOT, tick_hz=1000000, period=10000000)
[1973.026493 0.997927] 12:37:35:02 0.004506667 0.0011272 -0.39968 26.58251 Timer(mode=ONE_SHOT, tick_hz=1000000, period=6003000) Timer(mode=ONE_SHOT, tick_hz=1000000, period=10000000)
[1974.047708 1.021215] 12:37:36:03 0.0001566662 0.0011253 -0.39968 26.58251 Timer(mode=ONE_SHOT, tick_hz=1000000, period=6003000) Timer(mode=ONE_SHOT, tick_hz=1000000, period=10000000)
[1974.961448 0.913740] 12:37:37:00 0.002166667 0.0011375 -0.39968 26.58251 None Timer(mode=ONE_SHOT, tick_hz=1000000, period=10000000)
[1975.976106 1.014658] 12:37:38:01 0.001056666 0.0011459 -0.39968 26.58251 None Timer(mode=ONE_SHOT, tick_hz=1000000, period=10000000)
[1977.015479 1.039373] 12:37:39:02 0.001086666 0.0011313 -0.39968 26.58251 None Timer(mode=ONE_SHOT, tick_hz=1000000, period=10000000)
[1977.953503 0.938024] 12:37:40:00 0.0005466668 0.0011416 -0.39968 26.58251 None Timer(mode=ONE_SHOT, tick_hz=1000000, period=10000000)
[1978.969227 1.015724] 12:37:41:00 0.001116667 0.0011444 -0.39968 26.58251 None Timer(mode=ONE_SHOT, tick_hz=1000000, period=10000000)
[1979.964200 0.994973] 12:37:42:00 0.000636667 0.0011242 -0.39968 26.58251 None Timer(mode=ONE_SHOT, tick_hz=1000000, period=10000000)
[1980.988200 1.024000] 12:37:43:01 6.666407e-06 0.0011095 -0.39968 26.58251 None Timer(mode=ONE_SHOT, tick_hz=1000000, period=10000000)
[1982.004757 1.016557] 12:37:44:02 -5.333312e-05 0.0010961 -0.39968 26.58251 None Timer(mode=ONE_SHOT, tick_hz=1000000, period=10000000)
[1983.018508 1.013751] 12:37:45:02 6.666687e-05 0.0011007 -0.39968 26.58251 None Timer(mode=ONE_SHOT, tick_hz=1000000, period=10000000)
[1984.015306 0.996798] 12:37:46:02 0.001386667 0.0010837 -0.39968 26.58251 None Timer(mode=ONE_SHOT, tick_hz=1000000, period=10000000)
[1984.988131 0.972824] 12:37:47:00 0.0008166665 0.0010591 -0.39968 26.58251 None Timer(mode=ONE_SHOT, tick_hz=1000000, period=10000000)
[1985.987488 0.999357] 12:37:48:01 0.0005766665 0.0010443 -0.39968 26.58251 None Timer(mode=ONE_SHOT, tick_hz=1000000, period=10000000)
[1987.003771 1.016283] 12:37:49:02 0.0003966661 0.0010258 -0.39968 26.58251 None Timer(mode=ONE_SHOT, tick_hz=1000000, period=10000000)
[1988.022267 1.018497] 12:37:50:02 0.0002766661 0.0010003 -0.39968 26.58251 None Timer(mode=ONE_SHOT, tick_hz=1000000, period=10000000)
[1989.015780 0.993512] 12:37:51:02 0.0002766661 0.0009593994 -0.39968 26.58251 None Timer(mode=ONE_SHOT, tick_hz=1000000, period=10000000)

```

mungewell, 2024-10-26:
Another example, were I modulate timer2 slightly when it is setup...
```
[1198.127973 0.969679] 22:51:55:00 0.2615867 0.2633127 -0.39968 26.58251 Timer(mode=ONE_SHOT, tick_hz=1000000, period=6003000) Timer(m
ode=ONE_SHOT, tick_hz=1000000, period=10014000)
[1199.183278 1.055305] 22:51:56:02 0.2632267 0.2633016 -0.39968 26.58251 Timer(mode=ONE_SHOT, tick_hz=1000000, period=6003000) Timer(m
ode=ONE_SHOT, tick_hz=1000000, period=10014000)
[1200.154580 0.971302] 22:51:57:01 0.2631766 0.2633023 -0.39968 26.58251 None Timer(mode=ONE_SHOT, tick_hz=1000000, period=10014000)
[1201.124361 0.969780] 22:51:58:00 0.2634166 0.2632997 -0.39968 26.58251 None Timer(mode=ONE_SHOT, tick_hz=1000000, period=10014000)
[1202.202419 1.078058] 22:51:59:02 0.2631967 0.263303 -0.39968 26.58251 None Timer(mode=ONE_SHOT, tick_hz=1000000, period=10014000)
[1203.171627 0.969208] 22:52:00:00 0.2625667 0.2632962 -0.39968 26.58251 None Timer(mode=ONE_SHOT, tick_hz=1000000, period=10014000)
[1204.228971 1.057344] 22:52:01:03 0.2623567 0.2632727 -0.39968 26.58251 Timer(mode=ONE_SHOT, tick_hz=1000000, period=6003000) Timer(mode=ONE_SHOT, tick_hz=1000000, period=10025000)
[1205.198417 0.969447] 22:52:02:02 0.2634667 0.2632707 -0.39968 26.58251 Timer(mode=ONE_SHOT, tick_hz=1000000, period=6003000) Timer(mode=ONE_SHOT, tick_hz=1000000, period=10025000)
[1206.166555 0.968138] 22:52:03:01 0.2628667 0.2632589 -0.39968 26.58251 Timer(mode=ONE_SHOT, tick_hz=1000000, period=6003000) Timer(mode=ONE_SHOT, tick_hz=1000000, period=10025000)
[1207.142656 0.976101] 22:52:04:00 0.2637067 0.2632538 -0.39968 26.58251 Timer(mode=ONE_SHOT, tick_hz=1000000, period=6003000) Timer(mode=ONE_SHOT, tick_hz=1000000, period=10025000)
[1208.221319 1.078663] 22:52:05:02 0.2638567 0.2632487 -0.39968 26.67614 Timer(mode=ONE_SHOT, tick_hz=1000000, period=6003000) Timer(mode=ONE_SHOT, tick_hz=1000000, period=10025000)
[1209.191378 0.970059] 22:52:06:01 0.2632267 0.2632587 -0.39968 26.67614 Timer(mode=ONE_SHOT, tick_hz=1000000, period=6003000) Timer(mode=ONE_SHOT, tick_hz=1000000, period=10025000)
[1210.157711 0.966333] 22:52:07:00 0.2632867 0.263242 -0.39968 26.67614 None Timer(mode=ONE_SHOT, tick_hz=1000000, period=10025000)
[1211.206338 1.048627] 22:52:08:02 0.2634767 0.2632387 -0.39968 26.67614 None Timer(mode=ONE_SHOT, tick_hz=1000000, period=10025000)
[1212.171052 0.964714] 22:52:09:01 0.2628967 0.2632426 -0.39968 26.67614 None Timer(mode=ONE_SHOT, tick_hz=1000000, period=10025000)
[1213.134869 0.963817] 22:52:10:00 0.2640367 0.2632369 -0.39968 26.58251 None Timer(mode=ONE_SHOT, tick_hz=1000000, period=10025000)
[1214.183943 1.049074] 22:52:11:02 0.2640067 0.2632406 -0.39968 26.58251 None Timer(mode=ONE_SHOT, tick_hz=1000000, period=10025000)
[1215.147570 0.963627] 22:52:12:00 0.2628367 0.2632442 -0.39968 26.58251 None Timer(mode=ONE_SHOT, tick_hz=1000000, period=10025000)
[1216.219328 1.071758] 22:52:13:03 0.2621167 0.263226 -0.39968 26.58251 None Timer(mode=ONE_SHOT, tick_hz=1000000, period=10025000)
[1217.198675 0.979347] 22:52:14:01 0.2641267 0.2632142 -0.39968 26.58251 None Timer(mode=ONE_SHOT, tick_hz=1000000, period=10025000)
[1218.163179 0.964504] 22:52:15:01 0.2631367 0.2631911 -0.39968 26.58251 None Timer(mode=ONE_SHOT, tick_hz=1000000, period=10025000)
[1219.127188 0.964009] 22:52:16:00 0.2625467 0.2631835 -0.39968 26.58251 None Timer(mode=ONE_SHOT, tick_hz=1000000, period=10025000)
```

Timer2 is stuck for the rest of the log, meaning that the timer interrupt did not trigger at what should have been the end of the 10s period (~1214.183943).

mungewell, 2024-10-26:
Have evidence to confirm that there is (was) an issue with the timers NOT triggering, or the interrupt being missed,

I added some protection and some "!!!!!" alerting/messaging
https://github.com/mungewell/pico-timecode/blob/main/pico_timecode.py#L277
```
    if timer == eng.timer3:
        # This should NEVER occur, it means previous timers were missed.
        print("!!!!!")
        if eng.timer1:
            eng.timer1.deinit()
        if eng.timer2:
            eng.timer2.deinit()
```

Unit 2: Occurs 11.5s after "7350s" which shows that the timers are reset shortly before this.... so why didn't Timer2 trigger?
```
[7347.038466 1.040454] 14:59:40:00 -0.01643333 -0.01713873 -0.39968 31.45111 None Timer(mode=ONE_SHOT, tick_hz=1000000, period=10027000)
[7348.071103 1.032637] 14:59:41:02 -0.01727333 -0.01712903 -0.39968 31.45111 None Timer(mode=ONE_SHOT, tick_hz=1000000, period=10027000)
[7349.040902 0.969799] 14:59:42:01 -0.01667333 -0.01712653 -0.39968 31.54474 None Timer(mode=ONE_SHOT, tick_hz=1000000, period=10027000)
[7350.078080 1.037178] 14:59:43:02 -0.01748334 -0.01715382 -0.39968 31.54474 Timer(mode=ONE_SHOT, tick_hz=1000000, period=6003000) Timer(mode=ONE_SHOT, tick_hz=1000000, period=10016000)
[7351.003724 0.925644] 14:59:44:00 -0.01778333 -0.01714962 -0.39968 31.63837 Timer(mode=ONE_SHOT, tick_hz=1000000, period=6003000) Timer(mode=ONE_SHOT, tick_hz=1000000, period=10016000)
[7352.039870 1.036146] 14:59:45:01 -0.01664333 -0.01715882 -0.39968 31.54474 Timer(mode=ONE_SHOT, tick_hz=1000000, period=6003000) Timer(mode=ONE_SHOT, tick_hz=1000000, period=10016000)
[7352.972244 0.932374] 14:59:46:00 -0.01682333 -0.01715142 -0.39968 31.45111 Timer(mode=ONE_SHOT, tick_hz=1000000, period=6003000) Timer(mode=ONE_SHOT, tick_hz=1000000, period=10016000)
[7354.027520 1.055276] 14:59:47:00 -0.01787333 -0.01715722 -0.39968 31.35748 Timer(mode=ONE_SHOT, tick_hz=1000000, period=6003000) Timer(mode=ONE_SHOT, tick_hz=1000000, period=10016000)
[7355.043512 1.015992] 14:59:48:01 -0.01682333 -0.01716623 -0.39968 31.35748 Timer(mode=ONE_SHOT, tick_hz=1000000, period=6003000) Timer(mode=ONE_SHOT, tick_hz=1000000, period=10016000)
[7356.083560 1.040047] 14:59:49:03 -0.01658334 -0.01716032 -0.39968 31.26385 None Timer(mode=ONE_SHOT, tick_hz=1000000, period=10016000)
[7357.037072 0.953513] 14:59:50:01 -0.01676333 -0.01716092 -0.39968 31.35748 None Timer(mode=ONE_SHOT, tick_hz=1000000, period=10016000)
[7357.973365 0.936292] 14:59:51:00 -0.01691333 -0.01715542 -0.39968 31.35748 None Timer(mode=ONE_SHOT, tick_hz=1000000, period=10016000)
[7359.001207 1.027843] 14:59:52:00 -0.01808333 -0.01716052 -0.39968 31.35748 None Timer(mode=ONE_SHOT, tick_hz=1000000, period=10016000)
[7360.042491 1.041284] 14:59:53:01 -0.01670333 -0.01716212 -0.39968 31.35748 None Timer(mode=ONE_SHOT, tick_hz=1000000, period=10016000)
[7361.104639 1.062148] 14:59:54:03 -0.01895333 -0.01718282 -0.39968 31.35748 None Timer(mode=ONE_SHOT, tick_hz=1000000, period=10016000)
[7361.414385 0.309746] !!!!!
[7362.031253 0.616868] 14:59:55:01 -0.01736333 -0.01717952 -0.39968 31.26385 Timer(mode=ONE_SHOT, tick_hz=1000000, period=6003000) Timer(mode=ONE_SHOT, tick_hz=1000000, period=10013000)
[7363.067486 1.036232] 14:59:56:02 -0.01715333 -0.01718302 -0.39968 31.35748 Timer(mode=ONE_SHOT, tick_hz=1000000, period=6003000) Timer(mode=ONE_SHOT, tick_hz=1000000, period=10013000)
[7363.990536 0.923050] 14:59:57:00 -0.01622333 -0.01718292 -0.39968 31.45111 Timer(mode=ONE_SHOT, tick_hz=1000000, period=6003000) Timer(mode=ONE_SHOT, tick_hz=1000000, period=10013000)
```

Unit 3 has Timer1 fail instead.
```
[4590.039782 1.032039] 14:13:47:02 -0.01439333 -0.01446434 -0.2110583 22.18203 Timer(mode=ONE_SHOT, tick_hz=1000000, period=7889000) Timer(mode=ONE_SHOT, tick_hz=1000000, period=10049000)
[4590.752297 0.712515] !!!
[4590.963127 0.210830] 14:13:48:00 -0.01463333 -0.01446674 -0.2110583 22.18203 Timer(mode=ONE_SHOT, tick_hz=1000000, period=7889000) Timer(mode=ONE_SHOT, tick_hz=1000000, period=10021000)
```

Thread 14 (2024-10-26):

Step in Phase with precisely calibrated unit(s)

mungewell, 2024-10-26:
Unexplained step in the phase monitoring with precisely calibrated, maybe this was always there but only visible now we have very low drift...

3 units monitored at same time, fed by single UltraSync One. 30fps.
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

Similar location, but NOT exactly. X-axis is the RX timecode (ie unit's sync'ed)

mungewell, 2024-10-26:
Here's the time stamps for the first drop into the '-0.01' region.
```
$ cut -d " " -f 3,4 ttyACM1/2024-10-26_10\:06\:08 | grep -m 1 "\-0.01" -
13:49:20:00 -0.01166333
$ cut -d " " -f 3,4 ttyACM2/2024-10-26_10\:06\:08 | grep -m 1 "\-0.01" -
13:51:01:02 -0.01238333
$ cut -d " " -f 3,4 ttyACM3/2024-10-26_10\:06\:08 | grep -m 1 "\-0.01" -
13:42:28:03 -0.01244333
```

Maybe something related to how the system reads the incoming LTC, it's a digital process... Though should stress this is a
very small step.

mungewell, 2024-10-28:
Well this plot of a (calibrated, but stock XTAL) unit seems to show that it's repeatable, and something to do with the zero crossing point.... again it's a tiny step, so perhaps it's not important.
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

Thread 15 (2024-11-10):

The Great Calibration Run of 2024-11-09

mungewell, 2024-11-10:
I ran two Pico units against my Sync-IO (clocked by a Sigma BGS26N black burst generator), firstly to calibrate and then to free-run (with average calibration) for over 16 hours.

Both units are 'improved' with a TCXO, but temperature in room was not controlled and has some change overnight.

After the test the units where **very close** to the reference Timecode:

- Unit T002 - ttyACM0 = 0.02911544 frames fast
- Unit T004 - ttyACM1 = 0.03665596 frames fast

Annotated summaries:
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

There is obviously some 'weirdness' in the later part of the test. But noting that this did not occur at the same time for the units...

mungewell, 2024-11-10:
I was also running my UltraSync One in parallel; it (like the Pico's) started in phase with the reference, but by the end of the test was significantly 'worse' - over one frame fast.
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

Note: the top 5300 has little arrow pointing to the right.... Timecode is way off!

It is impossible to know whether the calibration of UltaSync One or the BGS26N is the 'bad' one; but we can say that the Pico-Timecode units tracked the one that they were calibrated against.

mungewell, 2024-11-10:
With the 'zoom' function turned on, the bargraph shows that both units are 'ahead' of the reference time (ie the SyncIO is reported as 'behind'). The TC values on the OLED do NOT match the real situation, perhaps related to the 'weirdness' seen in the plot, something that needs more investigations.

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

mungewell, 2024-11-11:
For reference the calibration plots for Units were:
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

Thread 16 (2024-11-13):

Which 'Pico' to host Rev2.0 board?

mungewell, 2024-11-13:
I'd like to redesign the rev2.0 Pico-Timecode board to be as cost efficient as possible, so am reviewing Picos.... I could lay out a complete design with RP2040/RP2350, but that would make the build more difficult for others (and I don't think I want to be a manufacturer with all that entails).

There are the following, which are almost identical:
https://shop.pimoroni.com/products/tiny-2350?variant=42092638699603
https://shop.pimoroni.com/products/tiny-2040?variant=39560012300371
https://www.waveshare.com/product/rp2040-tiny.htm
https://www.waveshare.com/product/rp2040-zero.htm

The WaveShare have an extra pin per side, and the PiMoroni have the extra ground which would pull GPIO15 low on the WaveShare. Both differences seem workable.

18mm x 25mm is tiny!

That said the 'one connector' layout of the Rev1 board is about this size, though the PCB could be longer than the Pico's. We'd probably want to add battery charging, buttons and OLED connector to the mix.

Note: I've put out some suggestions for manufacturers to do custom/limited builds with XTCO (rather than XTAL). Anyone want to work with me on this?

xiaopeng12138, 2024-11-17:
Personally, I prefer the one from WaveShare because it's more likely to be found here in Germany and you can also get it at aliexpress for a pretty cheap price. It costs about 1.49 Euro each without shipping if you buy 3.

I'm wondering if it's possible to use an external RTC? I think an external clock would be more accessible to more people. Something like the DS3231 seems pretty good, and there's also some time code project based on it.

https://github.com/mitkunz/diy_timecode_generator
https://github.com/lydasia/openltc

mungewell, 2024-11-18:
@xiaopeng12138 I don't see the use/purpose of the RTC, wall-clock time has no connection with the TC that would be used in production. Actually value of TC is irrelevant, only that all devices have the same and that it counts forward at the same time.

By 'calibrating' the Pico's XTAL (or preferable TCXO) the frequency can be match to a few parts-per-billion.

xiaopeng12138, 2024-11-18:
@mungewell The RTC I mentioned uses TCXO, it's pretty accurate at +-3.5 ppm. I'm wondering if it's possible to use the clock from the DS3231 to calibrate the pico. (DS3231 costs only about 1€ - 3€ depending on where you get it.)

xiaopeng12138, 2024-11-18:
> @mungewell The RTC I mentioned uses TCXO, it's pretty accurate at +-3.5 ppm. I'm wondering if it's possible to use the clock from the DS3231 to calibrate the pico. (DS3231 costs only about 1€ - 3€ depending on where you get it.)

And one of the advantages of the DS3231 is that even if you turn off the pico itself, for example to change the batteries, etc., the timecode will not be lost. It will still be synchronized thanks to the onboard battery.

mungewell, 2024-11-18:
@xiaopeng12138 I wrote up how this project functions here:

mungewell, 2024-12-03:
Here's a draft schematic, if anyone cares...
[Rev2_draft.pdf](https://github.com/user-attachments/files/17986832/Rev2_draft.pdf)

The GPIO will have to be reallocated to suit the smaller Pico's.

mungewell, 2024-12-03:
BTW on the topic of syncing to 1Hz output from RTC: for fractional framerates, if DropFrame is enabled then I think that the 1Hz and 1PPS will perfectly align on the hour, and every 10minutes.

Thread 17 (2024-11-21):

Battery Operation - Schottky Diode and Thresholds

mungewell, 2024-11-21:
In my prototype I am using a Schottky diode to isolate/protect battery from (inadvertant) VBUS connections. The diode lets battery feed into VSYS with a 0.4V drop.

In 'hardware' powersave (with PIO blocks running in light sleep I got the following power run, with a 3.7V 1300mA.hr battery. MicroPython is built with my 'lightsleep()' patches and with UART REPL (USB disabled).

```
[10:49:46.119344 0.000001] Pico-Timecode v2.1+
[10:49:46.119975 0.000634] www.github.com/mungewell/pico-timecode
[10:50:01.705483 15.585507] 01:00:10.12 3.650414
[10:50:11.713315 10.007832] 01:00:20.12 3.642357
[10:50:18.139709 6.426393] Entering PowerSave
[10:50:21.881025 3.741317] 01:00:26.25 3.653435
[10:50:32.096287 10.215262] 01:00:26.25 3.6600j
[10:50:42.439622 10.343335] 01:00:26.25 3.664915
[10:50:52.719388 10.279766] 01:00:26.25 3.671764
...
[22:34:10.966750 10.295684] 01:00:26.25 3.006112
[22:34:21.262736 10.295985] 01:00:26.25 3.002486
[22:34:31.526668 10.263933] 01:00:26.25 2.999^Fj
[22:34:31.654631 0.127962] Powersave Exited
[22:34:41.838818 10.184187] 12:44:50.15 2.992415
[22:34:51.942102 10.103285] 12:45:00.20 2.973079
[22:35:02.141718 10.199619] 12:45:10.26 2.960994
[22:35:12.229614 10.087892] 12:45:20.29 2.946492
[22:35:22.381924 10.152311] 12:45:31.01 2.930782
[22:35:32.469646 10.087722] 12:45:41.05 2.911043
[22:35:42.557186 10.087534] 12:45:51.08 2.89211
[22:35:52.692863 10.135683] 12:46:01.13 2.875191
[22:36:02.797482 10.104620] 12:46:11.16 2.844978
[22:36:12.885209 10.087725] 12:46:21.19 2.809932
[22:36:22.988741 10.103536] 12:46:31.21 2.763606
[22:36:33.108672 10.119927] 12:46:41.24 2.70157
[22:36:43.212449 10.103778] 12:46:51.27 2.614533
[22:36:53.348299 10.135849] 12:47:02.03 2.526287
[22:37:03.495606 10.147305] 12:47:12.06 2.427568
[22:37:03.497739 0.002138] Traceback (most recent call last):
[22:37:03.501456 0.003717]   File "main.py", line 1077, in <module>
[22:37:03.505654 0.004198]   File "main.py", line 722, in OLED_display_thread
[22:37:03.510372 0.004717] NameError: name 'sys' isn't defined
[22:37:03.512659 0.002289] MicroPython v1.25.0-preview.26.gc4d7237a4.dirty on 2024-11-13; Raspberry Pi Pico with RP2040
[22:37:03.518298 0.005638] Type "help()" for more information.
[22:37:03.520475 0.002177] >>> ^@Pico-Timecode v2.1+
[22:37:33.170794 29.650313] www.github.com/mungewell/pico-timecode
[22:37:37.883977 4.713186] ^@Pico-Timecode v2.1+
```

So `10:49:46.119344` through to `22:37:03.495606` is 12hrs run time!

I had unit come out of 'powersave' so that it could flash a 'low battery' warning on the screen, this increased current draw and promptly discharge what's left of the battery. Improvements made last night will prevent the unit cycling on/off.

I think I will change the thresholds (at VSYS) to 3.2V warn and 2.8V shutdown. Note these are 0.4V below battery voltage.

mungewell, 2024-11-21:
[20241120_voltage.txt](https://github.com/user-attachments/files/17848720/20241120_voltage.txt)

mungewell, 2024-11-28:
here's some power measurements, with and without a display attached. Note during 'power save' the LTC output is still running, the screen is turned off and the CPU is jumping in/out of lightsleep while keeping FIFOs full.
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

Next step is to see if we can improve those, maybe by further lowering the SYS clock?

mungewell, 2024-11-28:
30MHz is too slow for loading FIFOs and causes an 'Underflow Error' to be triggered - maybe code can be optimized.
60MHz works, and shows a notable power saving.
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

With the 'Pico1.3 OLED' the screen is not able to keep up with 30fps (that code is async, so not a problem). I had already done a lot to optimize.

Other 'SSD1306' based screen seemed to faster though.... when I had previously fly wired it in.

mungewell, 2024-12-02:
I also tried with 48MHz; it almost works, or rather works for some time and then triggers the underflow.

This would have the advantage of being able to shut down one of the PLLs, whilst keeping USB and UART alive.

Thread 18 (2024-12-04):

Timecode over USB-HID

mungewell, 2024-12-04:
FujiFilm announced a FW upgrade to introduce compatibility with Ambient Lockit devices, talked about/demonstrated here:
https://youtu.be/C4O3qpItzw0?si=_slQyaDvqQGjLbxZ

Big question is whether this is an Open Standard, and whether 'we' could implement with PicoTimecode.

Micropython on the RP2040 now supports implementing USB devices (apparently):
https://github.com/micropython/micropython/blob/master/examples/usb/usb_simple_device.py

flummer, 2024-12-04:
I think it is MIDI time code that is used

https://ambient.de/en/products/acn-cl-lockit-timecode-und-syncgenerator (technical details tab)

mungewell, 2024-12-06:
@flummer Thanks for the link, I first saw mention of this in Instagram post - where they seem to say that you can use either USB-HID or MTC. Obviously USB-Midi Class and USB-HID are different things... I know you can convert MTC to TC (afterall my Sync-IO can do that), but I'm not sure how simple it would be for a Pico.
https://www.instagram.com/p/DCpGFQ6sQTD/?igsh=YXhvam1iaGRnYml1

I did find that there is a 'HID Usage' for a 'Time Sensor', and perhaps this is what they use. I'm not clear how one would relate fractional framerates and/or dropframe into that....
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

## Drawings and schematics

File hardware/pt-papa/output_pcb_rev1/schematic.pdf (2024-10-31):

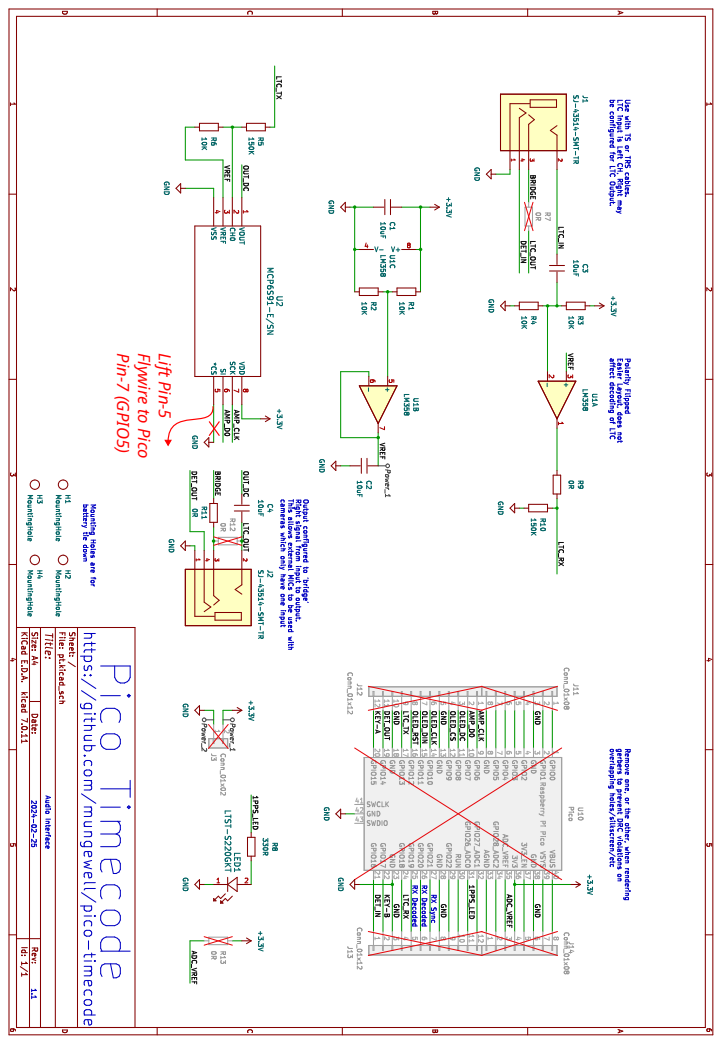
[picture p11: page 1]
Pin-7 (GPIO5); Lift Pin-5

Flywire to Pico

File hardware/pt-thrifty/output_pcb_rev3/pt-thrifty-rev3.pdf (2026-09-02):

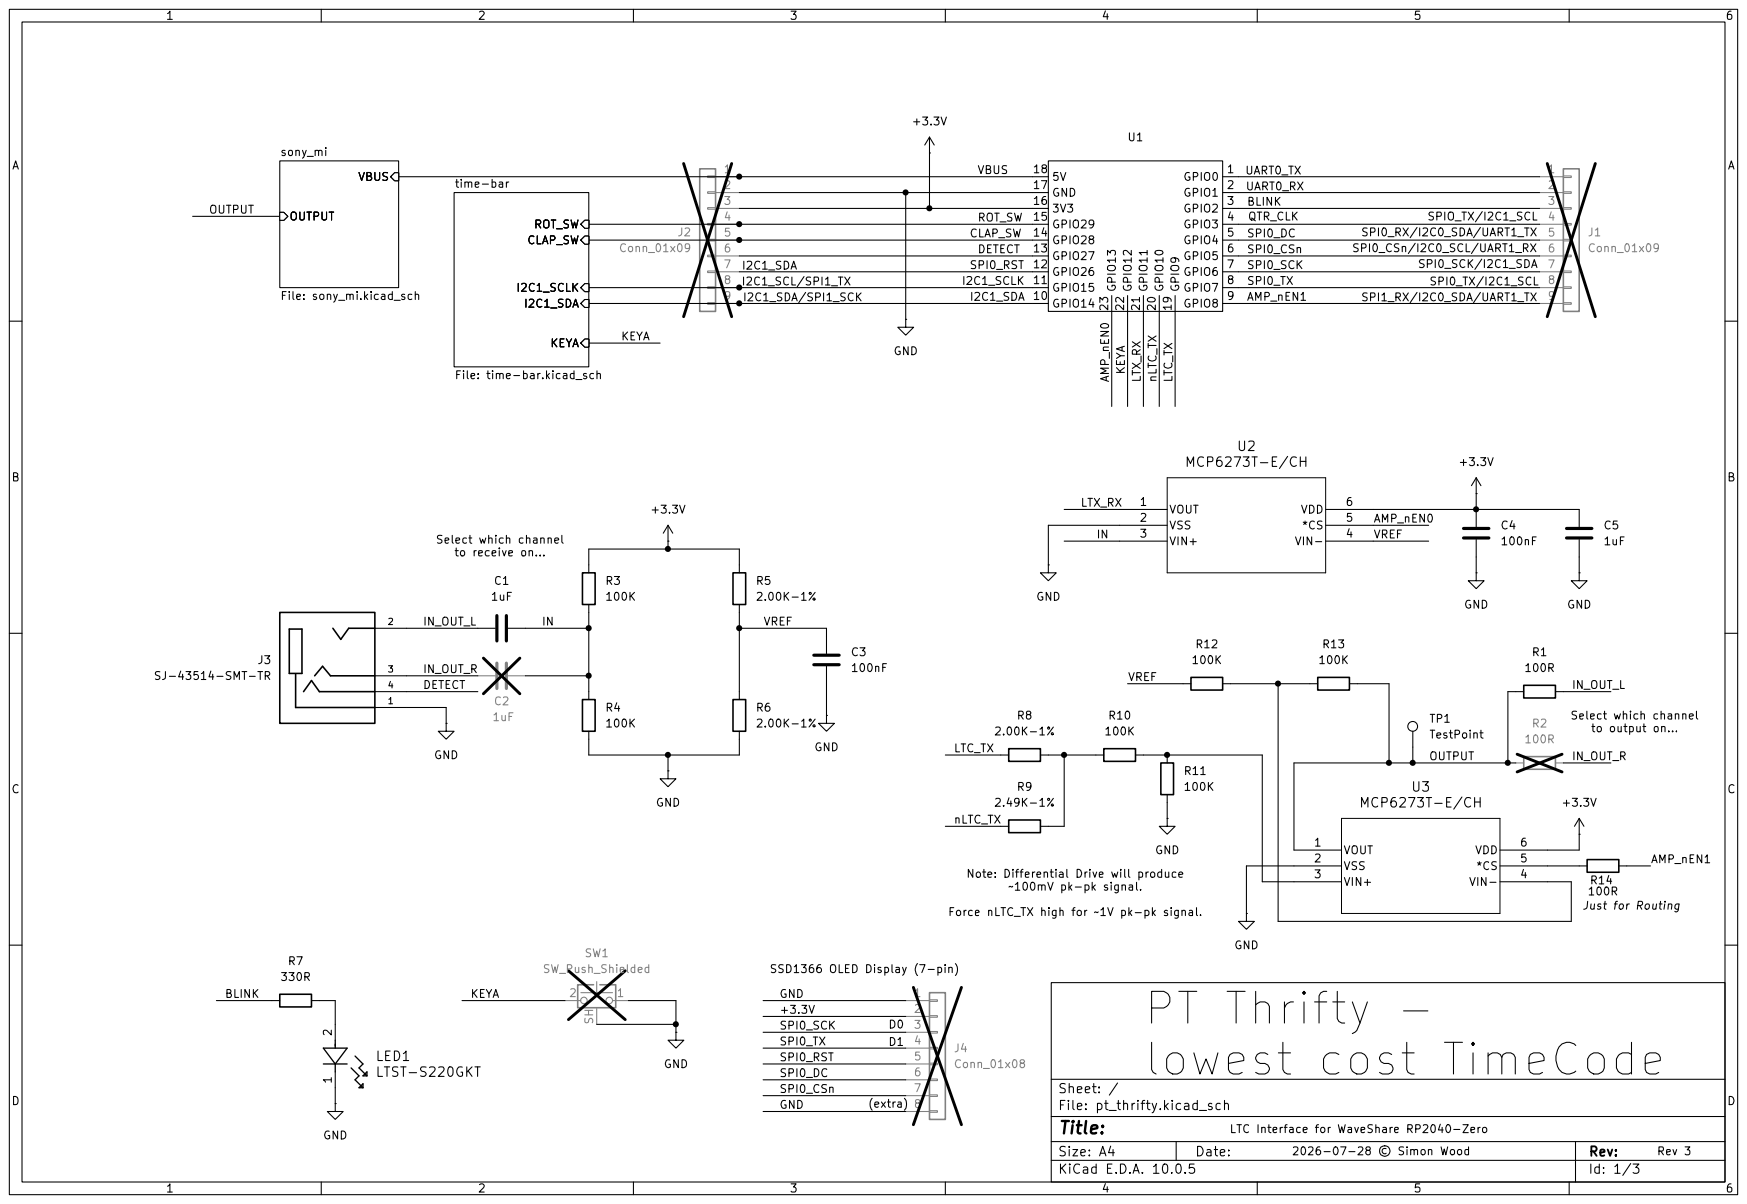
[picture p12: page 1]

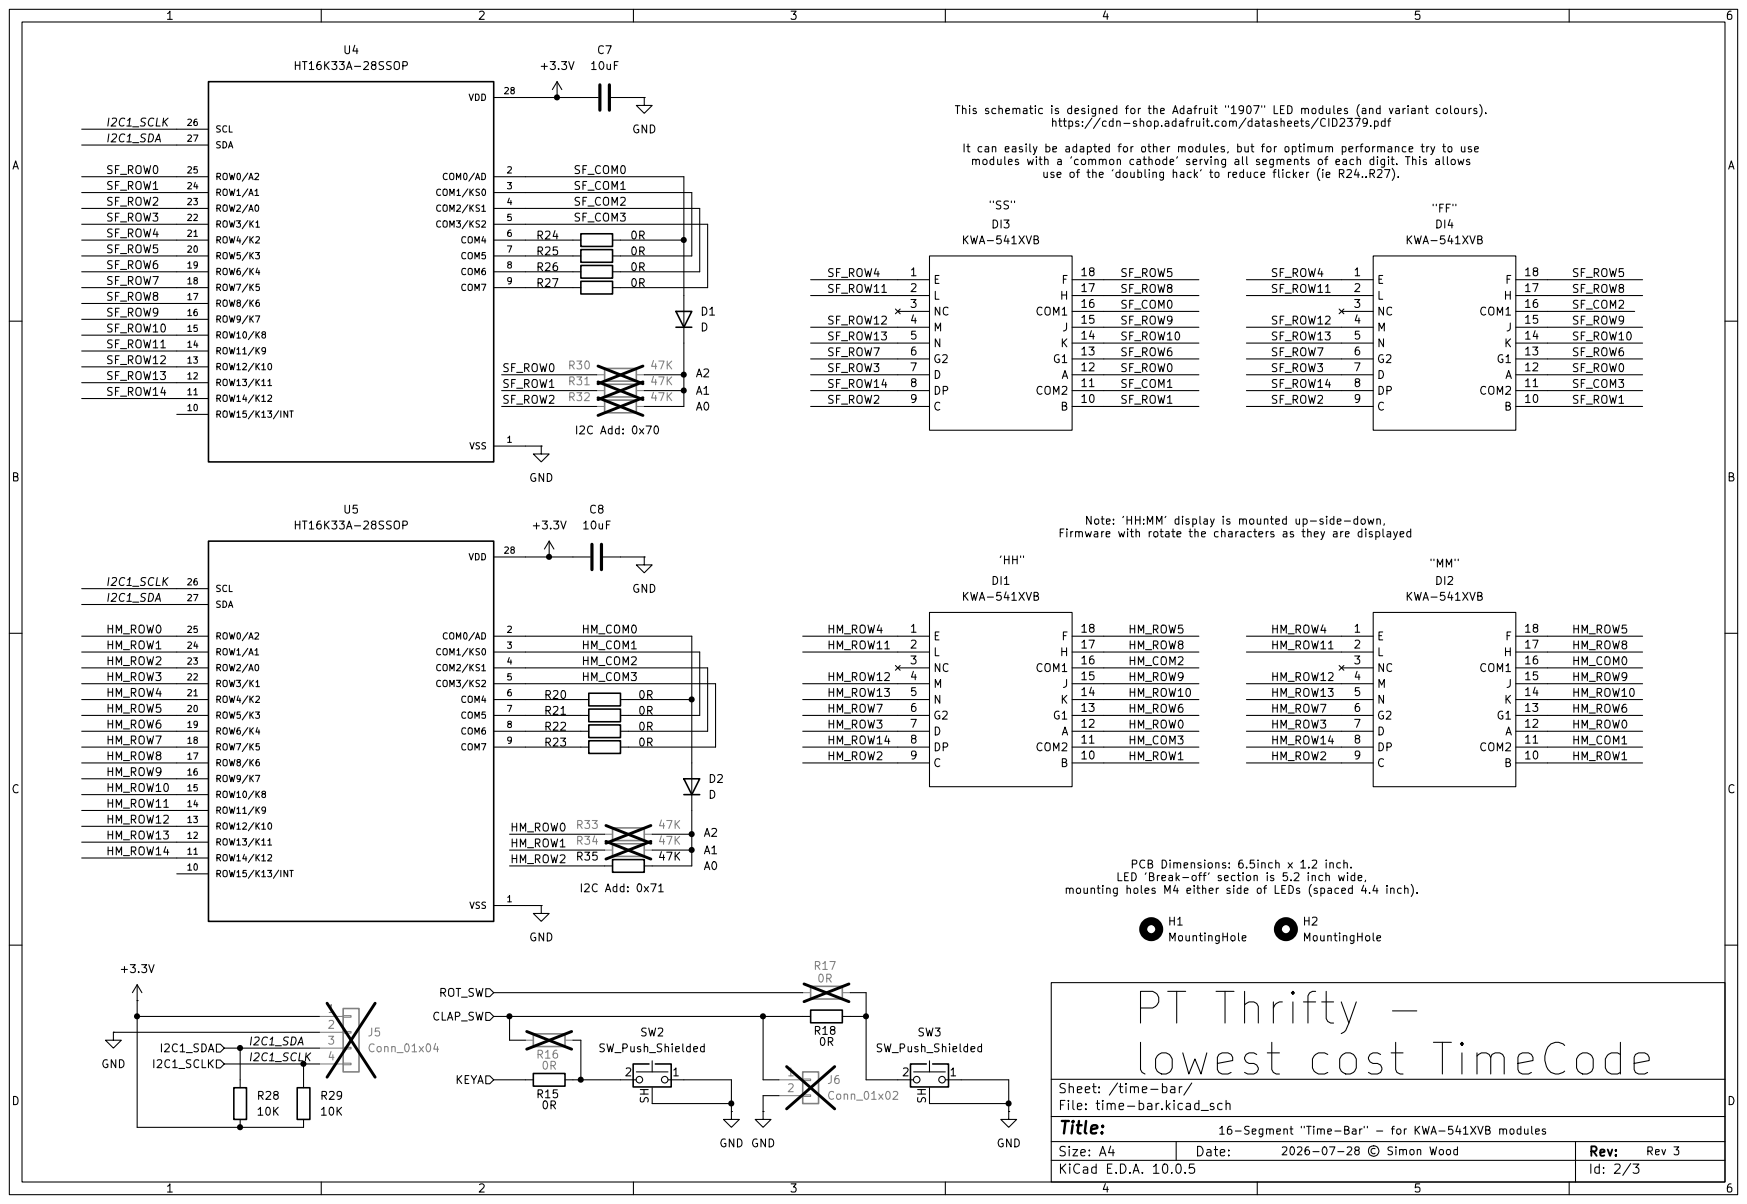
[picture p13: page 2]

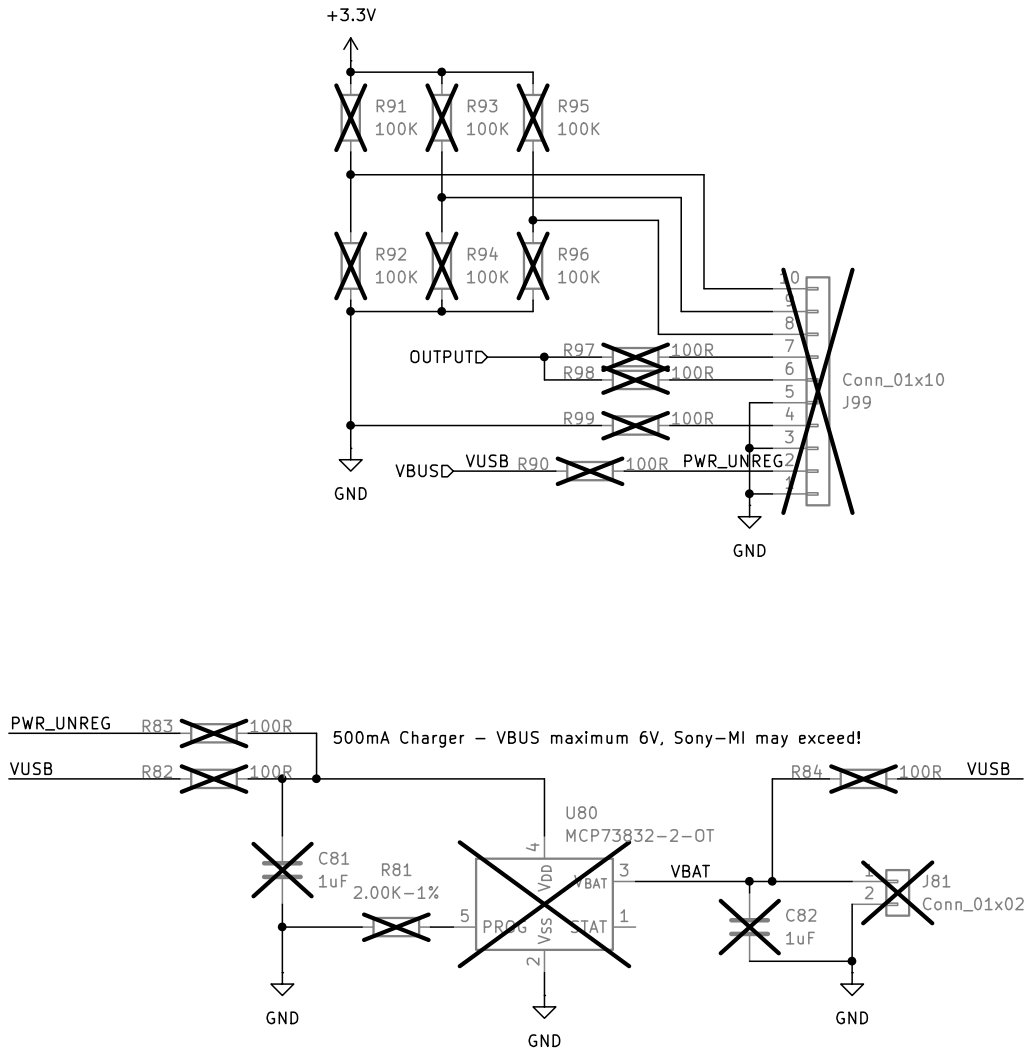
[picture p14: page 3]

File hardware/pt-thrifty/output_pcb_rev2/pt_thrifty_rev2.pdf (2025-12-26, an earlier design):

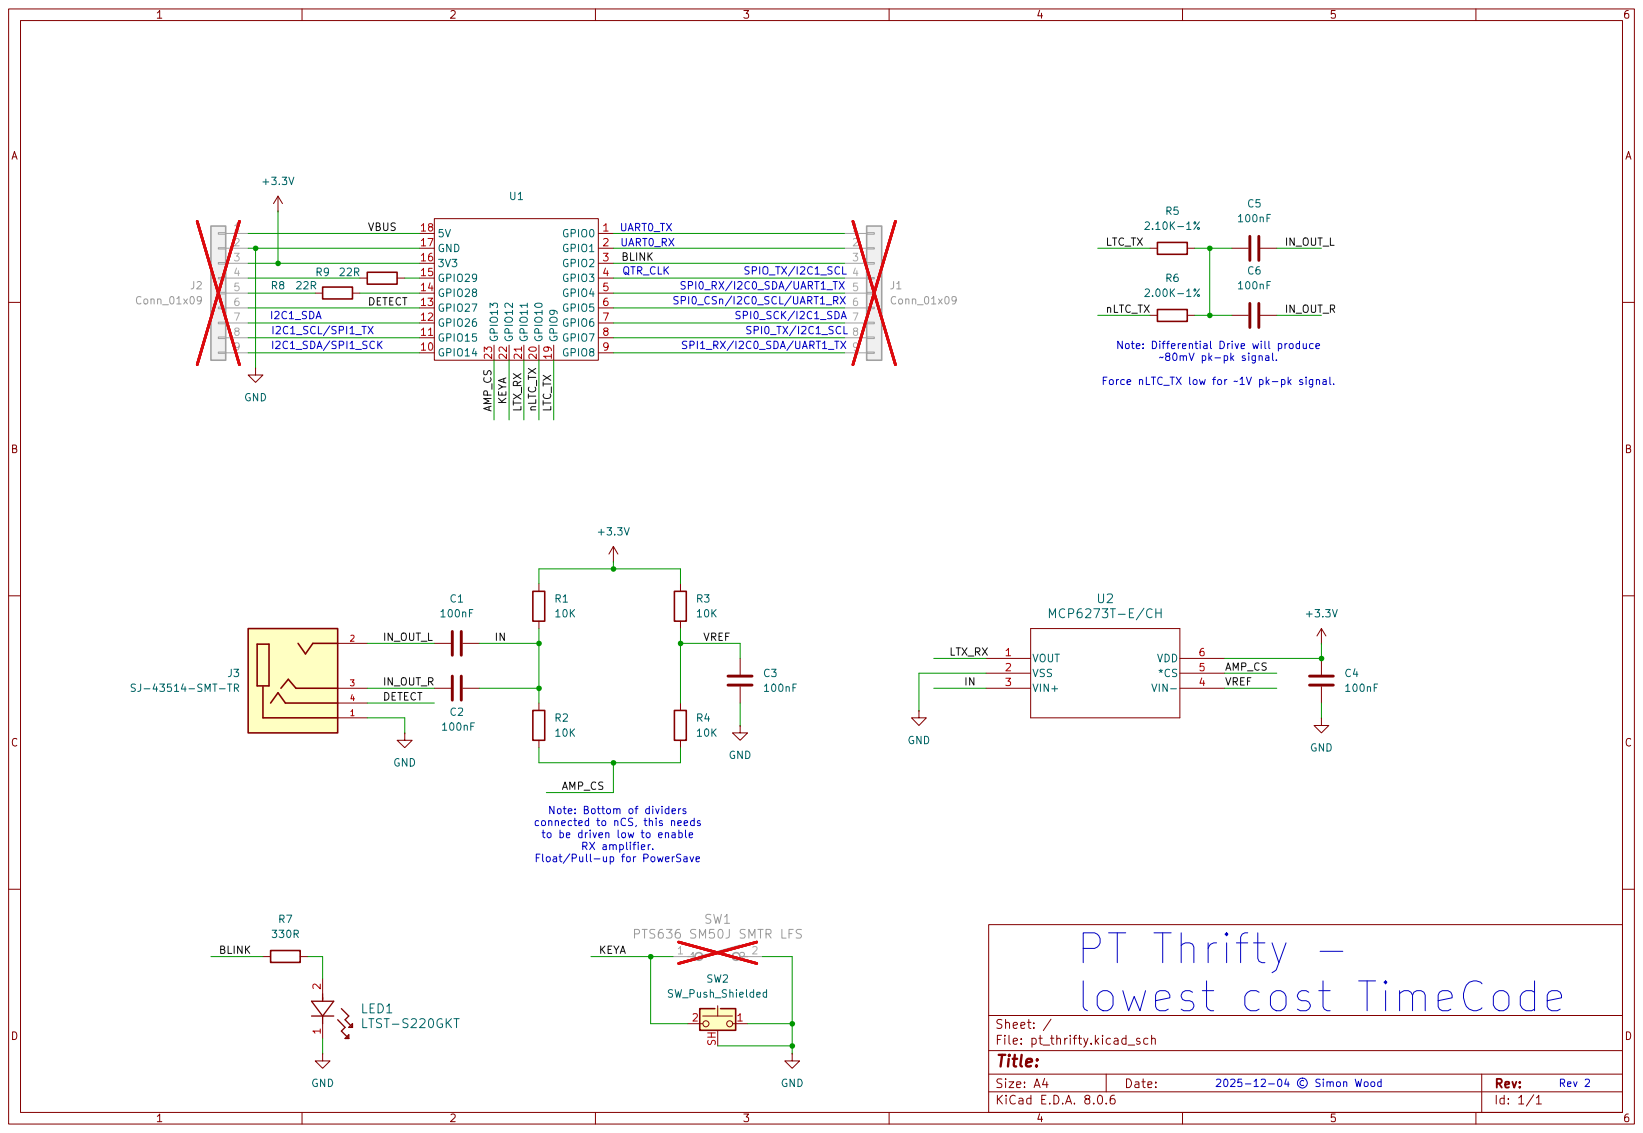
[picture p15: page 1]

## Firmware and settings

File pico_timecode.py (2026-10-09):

# Pico-Timcode for Raspberry-Pi Pico
# (c) 2023-05-05 Simon Wood <simon@mungewell.org>
#
# https://github.com/mungewell/pico-timecode

import _thread
import rp2

from machine import Timer, Pin, mem32, disable_irq, enable_irq, freq, lightsleep
from micropython import schedule, alloc_emergency_exception_buf, mem_info
from utime import sleep, ticks_us
from gc import collect, mem_free
from os import uname

# remember to do install lib to device
# 'mpremote mip install usb-device-midi'
try:
    import usb.device
    from usb.device.midi import MIDIInterface
    _hasUsbDevice = True
except ImportError:
    _hasUsbDevice = False
'''
_hasUsbDevice = False
'''


alloc_emergency_exception_buf(100)

VERSION="v3.3+"

# set up Globals
eng = None
stop = False

tx_raw = 0
rx_ticks = 0
rx_ticks_us = 0
tx_ticks_us = 0

mtc = None
quarters = 0

core_dis = [0, 0]

# Constants for run mode
HALTED  = -1
RUN     = 0
MONITOR = 1
JAM     = 64

# Constants for StateMachines
# PIO block 1
SM_START    = 0
SM_BLINK    = 1
SM_BUFFER   = 2
SM_ENCODE   = 3
# PIO block 2
SM_TX_RAW   = 4
SM_SYNC     = 5
SM_DECODE   = 6

irq_callbacks = [None]*8

timer1 = Timer()
timer2 = Timer()
timer3 = Timer()
tlock = _thread.allocate_lock()

#---------------------------------------------

# 'SM_START' State Machine
@rp2.asm_pio(autopull=True, autopush=True)

def auto_start():
    set(x, 0)
    nop()
    nop()
    irq(clear, 4)                   # immediately trigger Sync
                                    # --
    label("wait_for_low")           # loop length 4 clocks
    jmp(x_dec, "null1")
    label("null1")
    jmp(pin, "wait_for_low") [2]
                                    # --
    label("triggered")              # section length 4 clocks
                                    # capture count when pin goes low
    mov(isr, x)                     # mov X into ISR
    push(noblock)
    jmp(x_dec, "wait_for_high") [1]
                                    # --
    wrap_target()
    label("wait_for_high")          # loop length 4 clocks
    jmp(x_dec, "null2")
    label("null2")
    jmp(pin, "wait_for_low") [2]
    wrap()


# 'SM_START' State Machine
@rp2.asm_pio(autopull=True, autopush=True)

def start_from_sync():
    set(x, 0)
    wait(0, pin, 0)                 # Wait for pin to go low
    wait(1, pin, 0)                 # Wait for pin to go high

    irq(clear, 4)                   # Trigger Sync
                                    # --
    label("wait_for_low")           # loop length 4 clocks
    jmp(x_dec, "null1")
    label("null1")
    jmp(pin, "wait_for_low") [2]
                                    # --
    label("triggered")              # section length 4 clocks
                                    # capture count when pin goes low
    mov(isr, x)                     # mov X into ISR
    push(noblock)
    jmp(x_dec, "wait_for_high") [1]
                                    # --
    wrap_target()
    label("wait_for_high")          # loop length 4 clocks
    jmp(x_dec, "null2")
    label("null2")
    jmp(pin, "wait_for_low") [2]
    wrap()

# 'SM_BLINK' State Machine
@rp2.asm_pio(out_init=(rp2.PIO.OUT_HIGH,)*2, autopull=True,
        fifo_join=rp2.PIO.JOIN_TX, out_shiftdir=rp2.PIO.SHIFT_RIGHT)

def shift_led_irq_1x():
    irq(block, 4)                   # Wait for sync'ed start
                                    # ---
    wrap_target()                   # nominally 20 divisions per frame
    out(x, 6)                       # sub-total 1 cycle
                                    # ---
    label("next")
    out(pins, 2)                    # LEDs are bit-shifted pattern
                                    # each division should be ~128 cycles
                                    # representing each of the bits in packet
    jmp(pin, "skip_irq")            # sub-total 2 cycles
                                    # ---
    irq(rel(0)) [1]                 # set IRQ clocking quarter frame MTC data
                                    # _extra_ cycles 1x per frame = 2cycles
                                    # ---
    label("skip_irq")
    set(y, 3) [3]
    jmp(x_dec, "delay")             # sub-total 5 cycles
                                    # ---
    pull() [25]                     # last division only, fall through
    jmp(y_dec, "delay")             # sub-total 26 cycles
                                    # ---
    label("delay")
    jmp(y_dec, "delay") [29]        # sub-total 30 cycles
                                    # ---
    jmp(x_not_y, "next")            # sub-total 1 cycle
    wrap()                          # total 1 + 19(2+5+(4*30)+1) + (2+6+26+(3*30)+1) + 2
                                    # total 1 + (19 * 128) + 125 + 2

# 'SM_BLINK' State Machine
@rp2.asm_pio(out_init=(rp2.PIO.OUT_HIGH,)*2, autopull=True,
        fifo_join=rp2.PIO.JOIN_TX, out_shiftdir=rp2.PIO.SHIFT_RIGHT)

def shift_led_irq_4x():
    irq(block, 4)                   # Wait for sync'ed start
                                    # ---
    wrap_target()                   # nominally 20 divisions per frame
    out(x, 6)                       # sub-total 1 cycle
                                    # ---
    label("next")
    out(pins, 2)                    # LEDs are bit-shifted pattern
                                    # each division should be ~128 cycles
                                    # representing each of the bits in packet
    jmp(pin, "skip_irq")            # sub-total 2 cycles
                                    # ---
    irq(rel(0)) [4]                 # set IRQ clocking quarter frame MTC data
                                    # _extra_ cycles 4x per frame = 20cycles
                                    # ---
    label("skip_irq")
    set(y, 3) [2]
    jmp(x_dec, "delay")             # sub-total 4 cycles
                                    # ---
    pull() [27]                     # last division only, fall through
    jmp(y_dec, "delay")             # sub-total 29 cycles
                                    # ---
    label("delay")
    jmp(y_dec, "delay") [29]        # sub-total 30 cycles
                                    # ---
    jmp(x_not_y, "next")            # sub-total 1 cycle
    wrap()                          # total 1 + 19(2+4+(4*30)+1) + (2+4+29+(3*30)+1) + 20
                                    # total 1 + (19 * 127) + 126 + 20 = 2560 cycles

# 'SM_ENCODE' State Machine
@rp2.asm_pio(out_init=rp2.PIO.OUT_LOW)

def encode_dmc():
    irq(block, 4)                   # Wait for Sync'ed start

    wrap_target()
    label("toggle-0")
    mov(pins, invert(pins)) [14]    # Always toogle pin at start of cycle, "0" or "1"

    jmp(pin, "toggle-1")            # Check output of SM-1 buffer, jump if 1

    jmp("toggle-0") [15]

    label("toggle-1")
    mov(pins, invert(pins)) [15]    # Toggle pin to signal '1'
    wrap()

# 'SM_ENCODE' State Machine, multiple outs for differential output
@rp2.asm_pio(out_init=(rp2.PIO.OUT_LOW,)*2)

def encode_dmc2():
    irq(block, 4)                   # Wait for Sync'ed start

    wrap_target()
    label("toggle-0")
    mov(pins, invert(pins)) [14]    # Always toogle pin at start of cycle, "0" or "1"

    jmp(pin, "toggle-1")            # Check output of SM-1 buffer, jump if 1

    jmp("toggle-0") [15]

    label("toggle-1")
    mov(pins, invert(pins)) [15]    # Toggle pin to signal '1'
    wrap()

# 'SM_BUFFER' State Machine
@rp2.asm_pio(out_init=rp2.PIO.OUT_LOW, autopull=True,
             fifo_join=rp2.PIO.JOIN_TX, out_shiftdir=rp2.PIO.SHIFT_RIGHT)

def buffer_out():
    irq(block, 4)                   # Wait for Sync'ed start
    
    label("start")
    out(pins, 1) [30]
    
    jmp(not_osre, "start")
                                    # UNDERFLOW - when Python fails to fill FIFOs
    irq(rel(0))                     # set IRQ to warn other StateMachines
    wrap_target()
    set(pins, 0)
    wrap()

# ---

# 'SM_DECODE' State Machine
@rp2.asm_pio(set_init=(rp2.PIO.OUT_LOW,)*2)

def decode_dmc():
    label("previously_low")
    wait(1, pin, 0)         # Line going high
    irq(clear, 5) [19]      # trigger sync engine, and wait til 3/4s mark

    jmp(pin, "staying_high")
    set(pins, 3)            # Second transition detected (data is `1`)
    jmp("previously_low")   # Wait for next bit...

    label("staying_high")
    set(pins, 0)            # Line still high, no centre transition (data is `0`)
                            # |
                            # | fall through... a few cycles early
                            # V
    wrap_target()
    label("previously_high")
    wait(0, pin, 0)         # Line going Low
    irq(clear, 5) [19]      # trigger sync engine, and wait til 3/4s mark

    jmp(pin, "going_high")
    set(pins, 0)            # Line still low, no centre transition (data is `0`)
    jmp("previously_low")   # Wait for next bit...

    label("going_high")
    set(pins, 3)            # Second transition detected (therfore data is `1`)
    wrap()


# 'SM_SYNC' State Machine
@rp2.asm_pio(set_init=rp2.PIO.OUT_LOW, out_init=rp2.PIO.OUT_LOW,
             autopull=True, autopush=True, in_shiftdir=rp2.PIO.SHIFT_RIGHT)

def sync_and_read():
    out(y, 32)              # Read the expected sync word to Y, once only

    wrap_target()
    label("find_sync")
    mov(isr, x)             # force X value back into ISR, clears counter
    irq(block, 5)           # wait for input, databit ready
                            # Note: the following sample is from previous bit
    in_(pins, 2)            # Double clock input (ie duplicate bits)
    mov(x, isr)[10]

    jmp(x_not_y, "find_sync")
    set(pins, 0)

    set(x, 31)[8]           # Read in the next 32 bits
    mov(isr, null)          # clear ISR
    irq(rel(0))             # set IRQ for rx_ticks_us monitoring
    set(pins, 0)            # signal 'data section' start

    label("next_bit")
    in_(pins, 1)			# 1st should be 32 cycles after last IRQ
    jmp(x_dec, "next_bit")[30]

    set(x, 30)              # Read in the next 31 bits

    label("next_bit2")
    in_(pins, 1)
    jmp(x_dec, "next_bit2")[30]

    set(pins, 1)
    in_(pins, 1)			# Read last bit
    wrap()

# 'SM_TX_RAW' State Machine
@rp2.asm_pio(autopull=True, autopush=True)

def tx_raw_value():
    wrap_target()
    out(x, 32)                      # will 'block' waiting for TX timecode
    in_(x, 32)                      # and then write back into RX FIFO
    wrap()

# Purge the TX-FIFOs
@rp2.asm_pio(autopull=True,
        fifo_join=rp2.PIO.JOIN_TX, out_shiftdir=rp2.PIO.SHIFT_RIGHT)

def tx_fifo_purge():
    wrap_target()
    out(null, 1)
    wrap()

#-------------------------------------------------------
# handler for IRQs

def irq_handler(m):
    global eng, stop
    global tx_raw, rx_ticks_us, tx_ticks_us
    global core_dis
    global quarters, _hasUsbDevice

    core_dis[mem32[0xd0000000]] = disable_irq()
    ticks = ticks_us()

    if m==eng.sm[SM_BLINK]:
        # possible race condition, if FIFO is late to recieve data
        if quarters==0 and eng.sm[SM_TX_RAW].rx_fifo():
            # only read RX FIFO every 4th interrupt
            tx_raw = eng.sm[SM_TX_RAW].get()

        if _hasUsbDevice:
            quarters = (quarters + 1) & 0x03

        tx_ticks_us = ticks

    if m==eng.sm[SM_SYNC]:
        rx_ticks_us = ticks

    if m==eng.sm[SM_BUFFER]:
        # Buffer Underflow
        stop = 1
        eng.mode = HALTED

    # check/schedule any registered callbacks
    for i in range(len(eng.sm)):
        if irq_callbacks[i] and m==eng.sm[i]:
            schedule(irq_callbacks[i], i)
            '''
            # prevent "Uncaught exception in IRQ callback handler"
            # which I believe is due to code overloading the CPU,
            # but this will invalidate the actual timecode...
            try:
                schedule(irq_callbacks[i], i)
            except:
                pass
            '''

    enable_irq(core_dis[mem32[0xd0000000]])


def timer_sched(timer):
    schedule(timer_re_init, timer)

def timer_re_init(timer):
    global timer1, timer2, timer3, tlock
    global eng

    # do not re-init if engine is stopped
    if eng.is_stopped():
        return

    # timer1 means we are dithering between two values
    if timer == timer1:
        if eng.calval > 0:
            eng.dec_divider()
        else:
            eng.inc_divider()
        return

    if timer == timer2:
        eng.calval = eng.next_calval
        eng.config_clocks(eng.tc.fps, eng.calval)

        # are we dithering between two clock values?
        part = int(eng.period * (abs(eng.calval) % 1))

        tlock.acquire()
        timer1.deinit()
        timer2.deinit()
        timer3.deinit()

        if part == 0:
            # timers are no longer needed
            eng.timers = False
            tlock.release()
            return

        if True: #try:
            timer3.init(period=eng.period + 2000, mode=Timer.ONE_SHOT, callback=timer_sched)
            timer2.init(period=eng.period,        mode=Timer.ONE_SHOT, callback=timer_sched)
            timer1.init(period=eng.period - part, mode=Timer.ONE_SHOT, callback=timer_sched)
        '''
        except:
            # restart whole timer system
            timer = timer3
        '''
        tlock.release()

    if timer == timer3:
        # This should NEVER occur, it means previous timers were missed.
        print("!!!!")

        # restart whole timer system
        tlock.acquire()
        timer1.deinit()
        timer2.deinit()
        timer3.deinit()
        tlock.release()

        eng.timers = False
        schedule(eng.micro_adjust, eng.next_calval)

#---------------------------------------------

# https://web.archive.org/web/20240000000000*/http://www.barney-wol.net/time/timecode.html
# lookup this text in array, index is value used in TC

# SMPTE doc https://pub.smpte.org/doc/st309/20121005-pub/

tzs = [ \
    "+0000","-0100","-0200","-0300","-0400","-0500","-0600","-0700","-0800","-0900",    # 0x00..09
    "-0030","-0130","-0230","-0330","-0430","-0530",                                    # 0x0A..0F
    "-1000","-1100","-1200","+1300","+1200","+1100","+1000","+0900","+0800","+0700",    # 0x10..19
    "-0630","-0730","-0830","-0930","-1030","-1130",                                    # 0x1A..1F
    "+0600","+0500","+0400","+0300","+0200","+0100","Undef","Undef","TP-03","TP-02",    # 0x20..29
    "+1130","+1030","+0930","+0830","+0730","+0630",                                    # 0x2A..2F
    "TP-01","TP-00","+1245","Undef","Undef","Undef","Undef","Undef","+XXXX","Undef",    # 0x30..39
    "+0530","+0430","+0330","+0230","+0130","+0030"]                                    # 0x3A..3F


class timecode(object):
    def __init__(self):
        self.fps = 30.0
        self.df = False      # Drop-Frame
        self.enforce_parity = False

        # Alternate schemes for high FPS
        self.wide_ltc = False
        self.frame_pair = False

        # Timecode - starting value
        self.hh = 0
        self.mm = 0
        self.ss = 0
        self.ff = 0

        # Colour Frame flag
        self.cf = False

        # Clock flag
        self.bgf1 = False

        # User bits - format depends on BF2 and BF0
        self.bgf0 = True     # 4 ASCII characters
        self.bgf2 = False

        self.uf1 = 0xF       # 'PICO'
        self.uf2 = 0x4
        self.uf3 = 0x3
        self.uf4 = 0x4
        self.uf5 = 0x9
        self.uf6 = 0x4
        self.uf7 = 0x0
        self.uf8 = 0x5

        # Lock for multithreading
        self.lock = _thread.allocate_lock()

    def acquire(self):
        self.lock.acquire()

    def release(self):
        self.lock.release()

    def validate_for_drop_frame(self, reverse=False):
        self.acquire()
        if not reverse and self.df and self.ss == 0 and \
                (self.ff == 0 or self.ff == 1):
            if self.mm % 10 != 0:
                self.ff += (2 - self.ff)
        if reverse and self.df and self.ss == 0 and \
                (self.ff == 0 or self.ff == 1):
            if self.mm % 10 != 0:
                if self.hh == 0:
                    self.hh = 23
                else:
                    self.hh -= 1
                self.mm = 59                    # only happens on mm==0
                self.ss = 59
                self.ff = int(self.fps + 0.1) - 1
        self.release()

    def from_ascii(self, start="00:00:00:00", sep=True):
        # Example "00:00:00:00"
        #          hh mm ss ff
        #          01234567890

        # convert ASCII to 'raw' BCD array
        time = [x - 0x30 for x in bytes(start, "utf-8")]

        self.acquire()
        if sep == True:
            # only change DF if separators are given
            self.df = False

            self.hh = (time[0]*10) + time[1]
            self.mm = (time[3]*10) + time[4]
            self.ss = (time[6]*10) + time[7]
            self.ff = (time[9]*10) + time[10]

            if time[8] != 10:
                self.df = True
        else:
            self.hh = (time[0]*10) + time[1]
            self.mm = (time[2]*10) + time[3]
            self.ss = (time[4]*10) + time[5]
            self.ff = (time[6]*10) + time[7]
        self.release()

        if self.df:
            self.validate_for_drop_frame()
    
    def to_ascii(self, sep=True):
        self.acquire()
        if sep == True:
            time = [int(self.hh/10), (self.hh % 10), 10,
                    int(self.mm/10), (self.mm % 10), 10,
                    int(self.ss/10), (self.ss % 10),
                    (-2 if self.df == True else 10),    # use '.' for DF
                    int(self.ff/10), (self.ff % 10)]
        else:
            time = [int(self.hh/10), (self.hh % 10),
                    int(self.mm/10), (self.mm % 10),
                    int(self.ss/10), (self.ss % 10),
                    int(self.ff/10), (self.ff % 10)]
        self.release()

        new = ""
        for x in time:
            new += chr(x + 0x30)
        return(new)

    def from_raw(self, raw=0):
        self.acquire()
        self.df = (raw & 0x00000080) >> 7
        self.hh = (raw & 0x1F000000) >> 24
        self.mm = (raw & 0x003F0000) >> 16
        self.ss = (raw & 0x00003F00) >> 8
        self.ff = (raw & 0x0000003F)
        self.release()

    def to_raw(self):
        self.acquire()
        raw = (self.df << 7) + (self.hh << 24) + (self.mm << 16) + (self.ss << 8) + self.ff
        self.release()

        return raw

    def set_fps_df(self, fps=30.0, df=False):
        # should probably validate FPS/DF combo

        self.acquire()
        self.fps = fps
        self.df = df
        if fps > 39.0 and not self.wide_ltc and not self.frame_pair:
            # use 'wide_ltc' as default scheme
            self.wide_ltc = True
        self.release()

        if self.df:
            self.validate_for_drop_frame()

        return True

    def set_wide_ltc(self, wide_ltc=True):
        self.acquire()
        self.wide_ltc = wide_ltc
        if wide_ltc and self.frame_pair:
            self.frame_pair = False
        self.release()

    def set_frame_pair(self, frame_pair=True):
        self.acquire()
        self.frame_pair = frame_pair
        if frame_pair and self.wide_ltc:
            self.wide_ltc = False
        self.release()

    def enforce_parity(self, enforce_parity=True):
        self.acquire()
        self.enforce_parity = enforce_parity
        self.release()

    def next_frame(self, repeats=1):
        while repeats:
            repeats -= 1

            self.acquire()
            self.ff += 1
            if self.ff >= int(self.fps + 0.1):
                self.ff = 0
                self.ss += 1
                if self.ss >= 60:
                    self.ss = 0
                    self.mm += 1
                    if self.mm >= 60:
                        self.mm = 0
                        self.hh += 1
                        if self.hh >= 24:
                            self.hh = 0
            self.release()

            if self.df:
                self.validate_for_drop_frame()

    def prev_frame(self, repeats=1):
        while repeats:
            repeats -= 1

            self.acquire()
            self.ff -= 1
            if self.ff < 0:
                self.ff = int(self.fps + 0.1) - 1
                self.ss -= 1
                if self.ss < 0:
                    self.ss = 59
                    self.mm -= 1
                    if self.mm < 0:
                        self.mm = 59
                        self.hh -= 1
                        if self.hh < 0:
                            self.hh = 23
            self.release()

            if self.df:
                self.validate_for_drop_frame(True)

    # parity check, count 1's in 32-bit word
    def lp(self, b):
        c = 0
        for i in range(32):
            c += (b >> i) & 1

        return(c)

    def to_ltc_packet(self, send_sync=False, release=True):
        f27 = False
        f43 = False
        f59 = False

        self.acquire()
        if self.fps == 25.0 or self.fps == 50.00:
            f27 = self.bgf0
            f43 = self.bgf2
        else:
            f43 = self.bgf0
            f59 = self.bgf2

        if self.frame_pair:
            ff = self.ff >> 1
        else:
            ff = self.ff

        p = []
        p.append((self.uf2 << 12) + (self.cf  << 11) + (self.df << 10) +
                ((int(ff/10) & 0x3) << 8) +
                (self.uf1 << 4) + (ff % 10) +
                (self.uf4 << 28) + (f27 << 27) +
                ((int(self.ss/10) & 0x7) << 24) +
                (self.uf3 << 20) + ((self.ss % 10) << 16))

        p.append((self.uf6 << 12) + (f43 << 11) +
                ((int(self.mm/10) & 0x7) << 8) +
                (self.uf5 << 4) + (self.mm % 10) +
                (self.uf8 << 28) + (f59 << 27) + (self.bgf1 << 26) +
                ((int(self.hh/10) & 0x3) << 24) +
                (self.uf7 << 20) + ((self.hh % 10) << 16))
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

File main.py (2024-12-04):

# Pico-Timcode for Raspberry-Pi Pico
# (c) 2023-05-08 Simon Wood <simon@mungewell.org>
#
# https://github.com/mungewell/pico-timecode

# Basic UI implemented on hardware with 'Pico-OLED-1.3'
#
# Pico-OLED-1.3 is connected as follows:
# Pin9  / GP6  - I2C_SDA (not actually used)
# Pin10 / GP7  - I2C_CLK (not actually used)
# Pin11 / GP8  - OLED_DC
# Pin12 / GP9  - CS
# Pin14 / GP10 - OLED_CLK
# Pin15 / GP11 - OLED_DIN
# Pin17 / GP13 - RESET
# Pin20 / GP15 - User key 'A'
# Pin22 / GP17 - User key 'B'
#
# GP25 - Onboard LED
#
# We'll allocate the following to the PIO blocks:
#
# GP18 - RX: LTC_INPUT  (physical connection)
# GP19 - RX: raw/decoded LTC input (debug)
# GP20 - ditto - Hack to accomodate running out of memory
# GP21 - RX: sync from LTC input (debug)
#
# Pin29 / GP22 - TX: raw LTC bitstream output (debug)
# Pin17 / GP13 - TX: LTC_OUTPUT (physical connection)
#
# In PCB Rev1 we will also use:
#
# Pin19 / GP14 - OUT_DET (shorted to GND when J1 is connected)
# Pin21 / GP16 - IN_DET (shorted to GND when J2 is connected)
# Pin32 / GP26 - BLINK_LED (additional LED on front of PCB, near J1)
#
# For controlling the Output Amp:
#
# Pin7  / GP5  - ENABLE (fly wire as PCB error)
# Pin14 / GP10 - Shared with OLED_CLK
# Pin15 / GP11 - Shared with OLED_DIN
#
# In the future we may also use the I2C bus to 'talk' to other devices...
#

# We need to install the following modules
# ---
# https://github.com/aleppax/upyftsconf
# https://github.com/m-lundberg/simple-pid
# https://github.com/plugowski/umenu
# https://github.com/jrullan/micropython_neotimer
# https://github.com/mungewell/pico-oled-1.3-driver/tree/pico_timecode

from libs import config
from libs.pid import *
from libs.umenu import *
from libs.neotimer import *
from libs.lowpower import *

# Requires modified lib
# https://github.com/mungewell/pico-oled-1.3-driver/tree/pico_timecode

from libs.PicoOled13 import *

# Special font, for display the TX'ed timecode in a particular way
from libs.fonts import TimecodeFont
from framebuf import FrameBuffer, MONO_HMSB

import pico_timecode as pt

from machine import Pin,SPI,ADC,freq,reset
import _thread
import utime
import rp2
import gc

# Set up (extra) globals
outamp = None
menu = None
powersave = False
zoom = False
monitor = False
calibrate = False
menu_hidden = True

displayfps = None
calibration = None

def add_more_state_machines():
    sm_freq = int(pt.eng.tc.fps * 80 * 32)

    # TX State Machines
    pt.eng.sm.append(rp2.StateMachine(1, pt.blink_led2, freq=sm_freq,
                               set_base=Pin(25)))       # LED on Pico board + GPIO26/27/28
    pt.eng.sm.append(rp2.StateMachine(2, pt.buffer_out, freq=sm_freq,
                               out_base=Pin(22)))       # Output of 'raw' bitstream
    pt.eng.sm.append(rp2.StateMachine(3, pt.encode_dmc, freq=sm_freq,
                               jmp_pin=Pin(22),
                               in_base=Pin(13),         # same as pin as out
                               out_base=Pin(13)))       # Encoded LTC Output

    # RX State Machines
    pt.eng.sm.append(rp2.StateMachine(4, pt.decode_dmc, freq=sm_freq,
                               jmp_pin=Pin(18),         # LTC Input ...
                               in_base=Pin(18),         # ... from 'other' device
                               set_base=Pin(19)))       # Decoded LTC Input
    pt.eng.sm.append(rp2.StateMachine(5, pt.sync_and_read, freq=sm_freq,
                               jmp_pin=Pin(19),
                               in_base=Pin(19),
                               out_base=Pin(21),
                               set_base=Pin(21)))       # 'sync' from RX bitstream

    # correct clock dividers
    pt.eng.config_clocks(pt.eng.tc.fps)

    # set up IRQ handler
    for m in pt.eng.sm:
        m.irq(handler=pt.irq_handler, hard=True)

def apply_calibration():
    global displayfps, calibration

    period = None
    try:
        period = config.calibration['period']
    except:
        pass
    if period != None:
        try:
            calibration = config.calibration[displayfps]
            pt.eng.micro_adjust(calibration, period * 1000) # in ms
        except:
            pass


#---------------------------------------------
# Class for Custom Editing of Userbits/Name

class EditString(CustomItem, CallbackItem):

    def __init__(self, title, string, callback, \
                    alphabet=["0", "1", "2", "3", "4", "5", "6", "7", "8", "9"], \
                    selected=None, visible=None):
        super().__init__(title, visible=visible)
        self.callback = callback
        self.selected = None

        self.value = string
        self.alphabet = alphabet
        self.pos = 0

        self.items = []
        for i in range(len(string)):
            v = 0
            for j in range(len(self.alphabet)):
                if string[i] == self.alphabet[j]:
                    v = j
            self.items.append(v)

    def down(self):
        self.pos +=1
        if self.pos >= len(self.items):
            self.pos = -2
        self.draw()

    def select(self):
        if self.pos == -2:
            string = ""
            for i in range(len(self.items)):
                string += self.alphabet[self.items[i]]
            self.value = string
            return self.parent
        elif self.pos == -1:
            return self.parent
        else:
            self.items[self.pos] += 1
            if self.items[self.pos] >= len(self.alphabet):
                self.items[self.pos] = 0
        return self

    def draw(self):
        self.display.fill(0)

        for i in range(len(self.items)):
            self.display.text(self.alphabet[self.items[i]], 10*i, 15 if i == self.pos else 20, 1)

        if self.pos == -2:
            self.display.text("SAVE", 100, 40)
        else:
            self.display.text("save", 100, 40)

        if self.pos == -1:
            self.display.text("CANCEL", 0, 40)
        else:
            self.display.text("cancel", 0, 40)
        self.display.show()

    @property
    def value(self):
        return self._value

    @value.setter
    def value(self, value):
        self._value = value
        self._call_callable(self.callback, self._value)


# Make menus loop back to first item (single button navigation)
class MenuLoop(Menu):
    def move(self, direction: int = 1):
        if direction > 1 and type(self.current_screen) is not ValueItem and \
                    type(self.current_screen) is not EditString:
            if self.current_screen.selected + 1 == self.current_screen.count():
                self.current_screen.selected = 0
                return

        self.current_screen.up() if direction < 0 else self.current_screen.down()
        self.draw()

#---------------------------------------------
# Class for controlling MCP6S91 programable Amp
# (as used on official PCB)
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

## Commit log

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2023-05-08 Fix to LTC bits and adding example samples
2023-05-10 A couple of fixes
    [pico_timecode.py]
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2023-05-12 Swap over in/out pins, fixes to speed up OLED
    [main.py, pico_timecode.py]
2023-05-13 Implement method to sense TX/RX timing, and validate RX before Jamming
    [main.py, pico_timecode.py]
2023-05-15 Improve the RX engine and Jamming accuracy
    [main.py, pico_timecode.py]
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2023-05-17 Button fix, prev_frame and attempt to fix interrupt bug
    [main.py, pico_timecode.py]
2023-05-19 More fixes to IRQ
    [main.py, pico_timecode.py]
2023-05-19 Automatically Jam if booted with 'B' pressed
    [main.py]
2023-05-21 Switch to using CPU clock of 120MHz for better PIO dividers
2023-05-31 Attempt to 'learn' clock correction with PID
    [main.py]
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2023-06-04 Attempt to fix for global variables
    [main.py, pico_timecode.py]
2023-06-05 Still trying to find crash
    [pico_timecode.py]
2024-02-04 Improve the timer code for modulating between two divider values
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2024-02-13 Implement new display library, better fonts and justified printing
2024-02-14 Make sure Jam Bar displays
    [main.py]
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2024-02-21 Add ability to adjust the frame when the LEDs flashes. UltraSync One uses 10...
2024-02-22 Fix Rolling class, switch math to measure frame phase in -0.5 to 0.5
    [main.py]
2024-02-23 Improvement to Rolling Class - prevent arrays being re-alloc'ed
    [main.py]
2024-02-25 Initial rev-1 hardware
    Note: not yet built/tested yet
    [pt.csv, pt.kicad_pcb, pt.kicad_sch]
2024-02-28 Improvements to Calibration
    Now automatically completes after 15mins and should be more stable
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2024-02-28 Add some test scripts for evaluating calibration process
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2024-02-29 Attempt to fix occasional memory issue
    [main.py]
2024-02-29 Ensure that the timers are cleared, maybe solves calibration
2024-03-01 Fix Jamming at boot, via config or button 'B'
    [main.py]
2024-03-04 Another attempt to fix calibration glitch
    Wait for 1min after completing Jam, to allow the rolling average buffer to fill
    [main.py]
2024-03-05 Ensure that 'dc' is the correct FPS
    [main.py]
2024-03-05 UltraSync One uses frame 11 to blink it's LED.
2024-03-05 Prevent indexing outside of array
    [pico_timecode.py]
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2024-03-08 Trigger Jam by holding 'B' for 3s
    [main.py]
2024-03-08 Fix for calibrate
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2024-03-12 Prevent Jam-shortcut when cable is not plugged
    [main.py]
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2024-03-14 Add powersave function to turn of the display after 30s, wake with button.
    Display on = 50mA, Display off = 30mA
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2024-03-17 Prevent glitches - interrupt can occur at any time
    [pico_timecode.py]
2024-03-17 Fix framecount for fractional framerates
    [pico_timecode.py]
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2024-03-22 Correctly init Timecode class
    [pico_timecode.py]
2024-03-22 Print error if there's one
2024-03-23 Purge after aborting jam/cal cycle
    [main.py]
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2024-10-19 Add small startup delay as issue with MicroPython v1.23.0
    [main.py]
2024-10-19 Turn on LED whilst waiting to Jam-Sync
    [pico_timecode.py]
2024-10-26 Bug #13 - Workaround for timers not triggering
    [pico_timecode.py]
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2024-10-29 Ensure calibration is set when jam is started from menu
    [main.py]
2024-10-29 More calibration glitches
2024-10-30 Add ability to flash LED at a particular TC, rather than every second
    ```
    # example for 'flashtime' in the future
    xc = timecode()
    xc.fps = eng.tc.fps
    xc.from_raw(eng.tc.to_raw()) # note: this has DF flag included
    for i in range(69):
    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
2024-11-11 Implement hardware powersave with special microPython build
    This demos the ability to 'lightsleep()' whilst keeping the PIO clocks
    running and __still__ producing LTC from the data stored in the FIFO.
    When enabled the power draw (on a bare Pico) drops from 3.8V @ 30mA
    to 3.8V @ 11mA.
    See:
    https://github.com/micropython/micropython/pull/16183
2024-11-11 Hardware powersave
    With Pico OLED 3.8V @ 54mA, drops to 3.8V @ 17mA in powersave.
2024-11-13 Workaround IRQ bug and shorted 'lightsleep()' to prevent underflows
    [pico_timecode.py]
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2024-11-16 Fix monitor mode operation
    [main.py]
2024-11-17 Archive PCB Rev1 outputs
    [pt.csv]
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2024-11-20 Add battery monitor and display warning when voltage is low
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2024-11-21 Implement low power turn off - use either button to restart
2024-11-23 Improve battery monitor, add 'Power Off' menu item (when TX stopped)
2024-11-26 Weird glitch: Pad 'def auto_start()' so that it's exactly same length as 'start_from_pin()'
    [pico_timecode.py]
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2024-11-27 Improve sync with pico thread, adjust calibration timing
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2024-11-29 Save a bit of power in Power Off
2024-11-30 Move DF bit in Raw, to work around MicroPython bug
    https://github.com/micropython/micropython/issues/16221
    [pico_timecode.py]
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2024-11-30 Add short cut to Jam with keyB
    [pico_timecode.py]
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2025-11-15 Fixes to timestamp mechanism, add phase display in text
    [pico_timecode.py]
2025-11-15 Improved LED blink uses shift register, saves 4 PIO addresses
2025-11-18 Add fallback to TX after Jamming
    [pico_timecode.py]
2025-11-18 Fix powersave operation
2025-11-22 Change width of LED count, so that bitstreams are aligned with end of ISR
2025-11-29 Attempt to fix some EOMEM errors
    [pico_timecode.py]
2025-11-29 First pass at calibration with new timer mechanism
2025-12-08 Add documentation for PT-Thrifty timecode device
    Document the features and operation of the PT-Thrifty timecode device, including user interface, output levels, FPS configuration, calibration, and debugging information.
2025-12-08 Add a script for validating calibration on the device(s).
2025-12-09 (Ab)use 2nd LED output to create quarter frame interrupts for MTC
2025-12-09 Add a little delay to let PC enumerate USB device
2025-12-09 Switch to using MTC led routine, outputs QuarterClk on GPIO3
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2025-12-09 Remove copyright statement and references to MTC led routine
2025-12-09 Document New Timer Method and calibration results
    Added details about the New Timer Method for measuring TX vs RX phase, including calibration results and script functionality.
2025-12-12 Add check on whether usb.device libs are installed
2025-12-17 Fix MTC FPS encoding
    [pico_timecode.py]
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2025-12-17 MTC fixes, pass 'raw' and sync to 0th quarter
    [pico_timecode.py, pt_thrifty.py]
2025-12-20 Trying to figure out why RUN doesn't after Cancel Jam...
    [pt_thrifty.py]
2025-12-26 Rename original board as 'pt-papa'
    [pt.csv, pt.kicad_pcb, pt.kicad_sch]
2025-12-26 Add hardware design files for pt-thrifty (rev2)
    [KiCAD_Custom_DRC_Rules_for_PCBWay.kicad_pcb, KiCAD_Custom_DRC_Rules_for_PCBWay.kicad_sch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]
2025-12-26 Tweak BOM for pt-thrifty
    [pt_thrifty.csv]
2025-12-26 Up CPU clock to 180MHz and change dividers appropriately
    [clocks.xls]
2025-12-27 Tweak to use the MTC led routing, but loose Pico's onboard LED
    [pt_papa.py]
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2026-01-01 Configure for 180MHz clock and MTC capable Pico-Timecode
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2026-01-05 Improve shutdown, fixes Run after Jam-Cancel bug
    [pico_timecode.py, pt_thrifty.py]
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2026-01-06 Fix timing of 'blink_led_irq' for the case without USB-device-lib (ie 1x irq per frame)
    [pico_slate.py, pico_timecode.py, pt_papa.py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]
2026-01-07 Update UI chart switching 'Line' output to 'longer flash'
2026-01-11 Add config setting for 'v1083' board where RGB is different order
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2026-01-17 Maybe fix the 'MIC level' output occasionally going higher than expected.
    [pt_thrifty.py]
2026-01-18 Re-arrange timer code so that new timers are not continously created
2026-01-20 Harden timers, but still glitches after 8 or so jams
    [pico_timecode.py]
2026-01-21 Another timer re-write trying to fix issues
    [pico_timecode.py]
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2026-01-27 A couple of fixes to make DIY/GPS experimentation easier
    [pico_timecode.py]
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2026-07-09 Harden code so it still works with no LED modules attached
2026-07-10 'LED blur' workaround
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2026-07-16 fix Klapper switch
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2026-07-23 Revise PT-Thrifty documentation for accuracy
    Updated PT-Thrifty documentation for clarity and accuracy, including notes on LED behavior, output levels, and calibration.
2026-07-24 Ensure Calibration timers are started and allow to start into Jam mode
    [check_calibration.py, pico_timecode.py, pt_papa.py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]
2026-07-25 Keep the 2nd (synced) Info flash short duration, for comparison
    [pt_thrifty.py]
2026-07-30 WIP pt-thrifty rev3 sch/pcb
    [pt_thrifty.kicad_pcb, pt_thrifty.kicad_sch]
2026-07-30 Add missing sch files
    [sony_mi.kicad_sch, time-bar.kicad_sch]
2026-08-04 Check values for 50/60fps
    [clocks.xls]
2026-08-04 Clean up the Kicad files for PT-Thrifty
    [pt_thrifty.kicad_pcb, pt_thrifty.kicad_sch, time-bar.kicad_sch]
2026-08-04 Re-import symbols into PCB layout
    [pt_thrifty.kicad_pcb, pt_thrifty.kicad_sch, time-bar.kicad_sch]
2026-08-04 Add 3D models and pin-1 markings
    [pt_thrifty.kicad_pcb, pt_thrifty.kicad_sch]
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2026-08-27 HighLevel output : nLTC needs to be forced high on Rev3 PCB
2026-08-27 Control the nCS pin of the TX amp on Rev3 PCB
2026-08-31 Ensure MTC full/long packet is sync'ed to odd frame
    ... so 1st short packet is even frame
    [pt_thrifty.py]
2026-09-01 MTC: force 'gc.collect()' to happen often/early to prevent missing MTC packets
    [pt_thrifty.py]
2026-09-02 MTC: Force Garbage collection every 4 frames
    This has side effect of delaying the 'F0 2x' message by ~4ms
2026-09-02 PCB Rev3 files
    Note: intermediate PCB expect Rev4 shortly
    [pt_thrifty-B_Cu.gbr, pt_thrifty-B_Mask.gbr, pt_thrifty-B_Paste.gbr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]
2026-09-03 MTC: disable automatic GC, forcing GC every 4 frames
2026-09-05 Re-arrange Userbit usage
    Note: if manually setting the current date, use either yyyymmdd or ddmmyy00.
2026-09-10 Revert order of Digit userbits, last typed in bg1
    [pico_timecode.py]
2026-09-14 Fix detection of RP204 vs RP2350
    [pico_timecode.py, pt_thrifty.py]
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2026-09-18 'Demo' mode, and use Pico-1's LED on GPIO25
2026-09-19 Skip NeoPixel test on 'v1083' boards
    [pt_thrifty.py]
2026-09-21 MTC: prevent long packet being sent on same clock as abort
    [pt_thrifty.py]
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2026-10-08 Fix glitch reading calibration for drop-frame fps
    [pt_papa.py]
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2026-10-09 Fix bugs with HighFrameRate modes
    [pico_timecode.py, pt_papa.py]
